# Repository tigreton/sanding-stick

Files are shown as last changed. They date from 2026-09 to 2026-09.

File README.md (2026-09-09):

# Sanding Stick — lijador modular paramétrico

Mango tipo bolígrafo + 14 cabezales intercambiables, para lijar impresiones 3D y
filigranas en madera. Impreso en Bambu Lab A1 Mini (180 × 180 × 180 mm).

**Diez versiones. Lo único que cambia entre ellas es cómo se engancha el cabezal.**
Formas, anchos, mangos y orientación de impresión son idénticos en las diez.

| | Unión | Gesto de cambio | Aguanta el tirón | Comprar algo |
|---|---|---|---|---|
| **v1** | Hexágono 6 AF a presión | tirar y empujar | regular | no |
| **v2** | Bayoneta de 1/4 de vuelta | meter y girar 90° | **sí, bloqueo axial** | no |
| **v3** | Rosca cuadrada Ø8 × paso 2 | 3 vueltas | **sí** | no |
| **v4** | Imán Ø6×3 + espiga en D | acercar | se separa al tirar | **15 imanes** |
| **v5** | Clip elástico de dos brazos | empujar hasta el clic | sí, hasta cierta fuerza | no |
| **v6** | Cola de milano transversal | deslizar hasta el clic | **sí, por geometría** | no |
| **v7** | Cono autoblocante de 12° | empujar y tirar | sí, por rozamiento | no |
| **v8** | Espiga y cuña transversal | meter y empujar la cuña | **sí, y regulable** | no |
| **v9** | Pinza cónica de cuatro dedos | meter y empujar el casquillo | **sí, y regulable** | no |
| **v10** | Doble espiga con clic | empujar hasta el clic | sí, pero espigas frágiles | no |

**Si sólo vas a imprimir una: la v2.** Es la única *probada* que combina cambio
rápido con bloqueo axial real, y no depende de comprar nada ni de que un brazo
elástico aguante mil ciclos.

**Si lo que te preocupa es que el cabezal se afloje lijando: la v6.** Es la única
cuya dirección de desmontaje no coincide con ninguna dirección de trabajo, y la
única en la que el tirón lo aguanta la forma —un destalonado— y no el rozamiento
ni un brazo elástico.

**Si no quieres calibrar nada: la v7.** Es la única sin holgura que acertar: un
cono se para donde le deja la interferencia y queda tocando en toda la
superficie, así que el error de impresión se convierte en profundidad de asiento
en vez de en juego. Sujeta por rozamiento, como la v1, pero sin el juego que
hace que la v1 se afloje.

**Si quieres poder reapretarla dentro de un año: la v8.** Es la única cuyo
apriete no lo fija un número del modelo sino cuánto empujas la cuña, con 7 mm de
recorrido por delante. A cambio es la que más debilita el cabezal.

La v9 hace lo mismo que la v8 sin pieza que se pueda perder, pero es la más
voluminosa y la que más pieza tiene que imprimir.

**La v10 es la que más superficie de apoyo tiene contra el hombro** —53,5 mm²,
que es lo que de verdad impide que el cabezal bascule— y la que menos exige a la
impresora: dos postes redondos y dos agujeros redondos. Pero **sus espigas son
frágiles**: se han roto dos veces durante la puesta a punto y aguantan 2,4 kg de
fuerza lateral contra los 8,8 de un vástago normal. La v6 da el 90 % de esa
corona con una parte macho maciza, así que para casi todo el mundo es mejor
opción.

Las v6 a v10 son nuevas y todavía no han pasado por la cama: empieza por su
`test_ajuste`.

Abre `visor_lijador.html` en el navegador para verlas y compararlas en 3D: están
las diez, con las tres piezas de la v8 y la v9 montadas. Se regenera con
`python3 web/_empaquetar.py` (sólo renderiza lo que falte; `--todo` desde cero).

---

## 1. Archivos

```
sanding_stick/
├── scad/
│   ├── sanding_stick.scad        v1 · hexágono a presión
│   ├── sanding_stick_v2.scad     v2 · bayoneta
│   ├── sanding_stick_v3.scad     v3 · rosca
│   ├── sanding_stick_v4.scad     v4 · imán
│   ├── sanding_stick_v5.scad     v5 · clip elástico
│   ├── sanding_stick_v6.scad     v6 · cola de milano transversal
│   ├── sanding_stick_v7.scad     v7 · cono autoblocante
│   ├── sanding_stick_v8.scad     v8 · espiga y cuña
│   ├── sanding_stick_v9.scad     v9 · pinza cónica
│   ├── sanding_stick_v10.scad    v10 · doble espiga
│   └── _generar_versiones.py     genera v2–v10 desde un esqueleto común
├── render.sh                     genera los STL de una versión o de todas (bash)
├── render.ps1                    lo mismo desde PowerShell, para Windows
├── test_rapido.sh                genera el kit de test mínimo → stl_test/
├── TEST_RAPIDO.md                qué imprimir para elegir enganche y formas
├── visor_lijador.html            visor 3D interactivo con las diez versiones (3 MB)
├── stl/                          STL a calidad final
├── preview_stl/vN/               18 piezas por versión, calidad de trabajo
├── png/                          renders de cada pieza
├── web/
│   ├── plantilla.html            el visor sin las mallas
│   ├── meshes.js                 170 mallas cuantizadas y comprimidas
│   └── _empaquetar.py            renderiza lo que falte y arma el visor
├── sanding_stick_v1.0.zip        instantánea congelada de la v1
├── sanding_stick_v1-v5.zip       instantánea de las cinco versiones
└── CHANGELOG.md · FUENTES.md · PUBLICAR.md · README.md · LICENSE
```

`preview_stl/` y `png/` no van al repositorio: se regeneran con `./render.sh`.
Sí están versionadas las diez piezas de calibración (`stl/vN/test_ajuste.stl`),
que es lo primero que hay que imprimir, guardadas como STL binario.

## 2. Lo que comparten las diez versiones

**El cabezal tiene que apoyar en el hombro del mango.** Es lo que impide que
bascule al lijar: sin apoyo va en voladizo sobre el vástago y el par lo mueve
dentro de la holgura. El hombro llega hasta Ø(12 − 2·`mango_chaflan_frontal`) y la
boca del cabezal acaba en Ø10,48 — así que **el chaflán frontal es un parámetro de
la unión, no un detalle estético**, y cada versión lo ajusta al avellanado de su
propia boca (la v2 lo baja a 0,3; la v1 apoya de sobra con 1,0).

Cuánta corona apoya de verdad en cada versión, integrado sobre la malla en el
plano de la boca y recortado a lo que alcanza el hombro:

| | Corona | |
|---|---:|---|
| **v10** doble espiga | **53,5 mm²** | dos taladros de Ø4,15 en vez de uno de Ø8,6 |
| **v6** cola de milano | **48,4 mm²** | la ranura ocupa poco del plano de la boca |
| v1 hexágono | 25,5 mm² | |
| v5 clip | 13,4 mm² | los dos planos dejan material cerca del eje |
| v8 cuña | 13,2 mm² | con `cun_avell` = 0,4 |
| v4 imán | 8,9 mm² | el plano de la chaveta en D |
| v9 pinza | 8,5 mm² | |
| v2 bayoneta | 1,6 mm² | apoya en filo, no en cara |
| v3 rosca | 0,0 mm² | |
| v7 cono | 0,0 mm² | **a propósito**: posiciona el cono, no el hombro |

Las tres últimas explican por sí solas por qué la v2 se aflojaba: su avellanado
de boca es más ancho que el borde que deja `cuerpo_chaflan`, así que la boca
acaba en filo y no en cara. Arreglarlo del todo pide bajar `cuerpo_chaflan` de
0,8 a 0,4, y eso son catorce cabezales a reimprimir — sigue pendiente. Las
versiones nuevas nacen ya con el avellanado ajustado.

### La falda exterior — `falda = 6`

Opción del esqueleto, no una versión: el cabezal se alarga 6 mm y envuelve por
fuera un tramo rebajado de la punta del mango (espiga Ø8,8, contrataladro Ø9,0).
Se activa con un parámetro y **vale para ocho de las diez uniones**:

```bash
openscad -o pala.stl -D 'pieza="cabezal"' -D falda=6 scad/sanding_stick_v2.scad
```

Hace dos cosas, y sólo una de ellas es un regalo:

**1 · Le devuelve la corona a las uniones que la tienen en filo.** Medido:

| | Corona | Inercia de la corona |
|---|---:|---:|
| v2 sin falda | 1,6 mm² | 22 mm⁴ |
| **v2 con falda** | **30,5 mm²** | **420 mm⁴** — 19 veces más |
| v6 sin falda | 48,5 mm² | 434 mm⁴ |
| v6 con falda | 27,2 mm² | 367 mm⁴ — un 15 % menos |
| v10 sin falda | 53,5 mm² | 415 mm⁴ |
| v10 con falda | 27,2 mm² | 367 mm⁴ — un 12 % menos |

Es decir: **rescate para la v2 a v5, y ligera pérdida para la v6 y la v10.** La
falda cambia un disco casi macizo por un anillo: gana radio y pierde área, y a
las que ya tenían disco no les compensa. No es una mejora universal.

**2 · Reduce a la mitad el basculamiento por holgura, y eso sí vale para todas.**
Sin falda, al cabezal lo guía sólo el taladro: 13 mm de base con 0,18 de holgura
son 1,59° de bamboleo. Con falda hay dos guías separadas, una a cada lado del
plano de la junta, y la base pasa de 13 a 19 mm: 0,84°.

**Lo que cuesta:** 6 mm más de herramienta y ~220 mm³ por cabezal (3,1 cm³ en los
catorce).

**No vale para la v7 ni para la v9.** En la v7 la corona de la falda apoyaría en
el hombro y le disputaría al cono el posicionamiento axial, que es justo lo que
esa unión evita a propósito. En la v9 es peor: el cono exterior de la pinza queda
enterrado 6 mm dentro de un tubo de Ø12 —medido, Ø11,12 a 7 mm de la boca— y el
casquillo no puede llegar a él.

Dos cotas de la falda están donde están por una razón, y las dos son el mismo
fallo de siempre: `falda_chaflan` no puede pasar de 0,3 ni `falda_ch_boca` de
0,3, porque con 0,6 y 0,8 los dos avellanados se comen la corona entera y la
boca vuelve a acabar en filo. `falda_pared` tampoco puede subir de 1,6: el
contrataladro tiene que ser más ancho que la hembra de la junta o no se puede
llegar a ella.

**La parte macho va en el mango y la hembra en el cabezal.** Es la decisión que
condiciona todo lo demás:

- Todos los cabezales se imprimen **planos, con la cara de lijado sobre la cama**.
  Esa cara sale lisa y perfectamente plana, que es lo que necesita para pegar la lija.
- Ningún cabezal necesita soportes en ninguna de las cinco versiones.
- El cuerpo del cabezal es Ø12 × 16 mm, enrasado con el mango, con el eje a 5,5 mm
  de la cama: eso deja un plano de apoyo de ~5 mm y se imprime estable.

**Catálogo de cabezales** (7 formas × 2 anchos):

| Cabezal | Cara útil | Para qué |
|---|---|---|
| Pala plana 0° | 16×40 / 8×40 | caras grandes, líneas de capa, planos largos |
| Pala 45° | 16×25 / 8×25 | chaflanes, romper aristas |
| Taco 90° | 16×16 / 8×16 | fondos y rincones, lijando a empuje |
| Triángulo | punta 30 / 22 mm | esquinas interiores, calados de marquetería |
| Prisma 3 caras | 3 caras de 16 / 8 | ranuras en V, molduras; tres caras útiles |
| Media caña convexa | R8 / R4 | interiores curvos, gargantas |
| Canal cóncavo | canal Ø12 / Ø5 | varillas, barrotes, cantos redondeados |

Cuando la cara es de 8 mm y el mango de 12, la paleta lleva un **hombro** que la
ensancha hasta Ø12 junto al cuerpo: refuerza el cuello, que es donde rompería.

**Tres mangos**, los tres compatibles con cualquier cabezal de su versión:

| | Envolvente | Volumen | Cómo se imprime |
|---|---|---|---|
| **recta** | Ø12 × 137 | 14,2 cm³ | de pie, con balsa |
| **ergonomica** | Ø11–14 × 137 | 15,2 cm³ | de pie, con balsa |
| **doble** | 149 × 12 × 9 | 11,9 cm³ | tumbado sobre la cara plana |

La variante doble tiene la parte macho en los dos extremos y un plano lateral: se
imprime en 9 mm de alto en vez de una torre de 137 mm, no rueda por la mesa y lleva
dos cabezales montados a la vez.

## 3. Las cinco uniones en detalle

### v1 · Hexágono a presión — `scad/sanding_stick.scad`

Espiga hexagonal de 6,00 mm entrecaras, 12 mm de agarre; hueco de 6,30 (holgura
0,15 mm por lado); chaflanes de 0,8 mm en espiga y boca. Seis caras planas impiden
que el cabezal gire al lijar de canto y estiran menos material que un cilindro.

*Calibrar:* `holgura`.

### v2 · Bayoneta de 1/4 de vuelta — `scad/sanding_stick_v2.scad`

Vástago Ø8,6 con dos ranuras en L; taladro Ø8,96 con dos tetones interiores. Se mete
a fondo y se gira 90° hasta el tope. **El canal no es horizontal: su techo baja
0,40 mm a lo largo del giro**, así que girar aprieta el cabezal contra el hombro del
mango. Es una cuña autoblocante y al entrar en el asiento pasa un resalte de
0,18 mm que se nota como un clic.

Los dos tetones van a ±90° del eje vertical, o sea horizontales sobre la cama:
ninguna de sus caras es un voladizo.

**El parámetro que decide si aguanta es `bay_juego_ax`** (0,05): el hueco que le
queda al tetón entre el suelo y el techo del canal. En la 2.0 valía 0,15 — más que
la propia muesca de retención — así que el tetón flotaba, la cuña no llegaba a
apretar y lijar de lado aflojaba la unión. Con 0,05, el tetón queda pinzado y la
muesca muerde 0,16 mm de verdad.

*Calibrar:* `bay_holgura` (0,18) para el ajuste radial. Si el giro va duro al final,
baja `bay_muesca` antes que nada; si baila, baja `bay_juego_ax`.

### v3 · Rosca cuadrada — `scad/sanding_stick_v3.scad`

Ø8 × paso 2, seis vueltas, filete cuadrado de 0,7 mm de profundidad. El perfil
cuadrado se imprime mucho mejor que el triangular (nada de puntas finas) y agarra
más superficie. Un piloto liso Ø8,6 × 2 centra antes de que la rosca engrane, y el
cabezal apoya en un hombro plano.

*Calibrar:* `ros_holgura` (0,25 radial) y `ros_hol_ax` (0,15 por flanco).

### v4 · Imán — `scad/sanding_stick_v4.scad`

Espiga Ø9 × 7,5 con una cara plana (chaveta en D) que impide el giro, y un imán de
neodimio **Ø6 × 3 mm** en la punta. Otro imán igual al fondo del taladro del cabezal,
a 0,3 mm del primero cuando está montado.

Necesitas 15 imanes: uno por mango y uno por cabezal. Se pegan con cianoacrilato.
**Acerca los dos imanes antes de encolar para marcar la polaridad** — si los pegas
al revés, el cabezal se repele.

*Calibrar:* `esp_holgura` (0,20). El alojamiento del imán es `mag_juego` = 0,20.

### v5 · Clip elástico — `scad/sanding_stick_v5.scad`

Vástago Ø8,6 partido por una ranura de 3,8 mm en dos brazos flexibles de 11,5 mm de
voladizo, cada uno con una pestaña de 0,6 mm que encaja en un rebaje interior del
cabezal. Rampas de 40° por los dos lados: entra y sale, no es un encaje permanente.
Dos caras planas laterales orientan la pieza y hacen de chaveta.

La deformación de trabajo del brazo es del **1,9 %** — recalculada con el método
que validó la rotura de la v10.0, tomando como voladizo la distancia real hasta la
pestaña y la sección real del brazo, que es un segmento circular y no un
rectángulo. Es tracción entre capas, así que **imprímelo en PETG**: en PLA está
por encima de donde rompe. Se salva de lo que le pasó a la v10.0 porque su brazo
tiene 13,2 mm² de sección contra los 2,9 de aquélla.

*Calibrar:* `snap_pest` (0,6). Si cuesta meterlo, baja a 0,5; si se suelta, sube a 0,7.

### v6 · Cola de milano transversal — `scad/sanding_stick_v6.scad`

La única unión de la familia que **no se enchufa**: el cabezal desliza de lado
sobre un carril de cola de milano en la punta del mango. Carril de 7,0 mm de
cresta × 5,0 de alto, flancos a 12° de la vertical, recorrido de 7,9 mm.

Las tres cosas que la hacen distinta:

**La dirección de desmontaje no es ninguna dirección de lijado.** Empujar y tirar
actúan a lo largo del mango; girar, alrededor de él. El cabezal sale
perpendicular a las dos, así que el propio gesto de lijar no puede desmontarlo.
Y con `cm_orient = 90` esa dirección es además la de la presión de lijado, que
mete el cabezal contra su tope en vez de sacarlo.

**El tirón lo aguanta la geometría, no el ajuste.** El destalonado de 12° hay que
romperlo para separar las piezas: no depende del rozamiento (v1, v4), ni de un
brazo elástico que se fatiga (v5), ni de que una holgura siga siendo la del
primer día. Un carril tampoco puede girar dentro de su ranura: el par de lijar de
canto lo bloquea la forma.

**Aprieta al final del recorrido.** El carril es cónico: la cresta se estrecha
0,7 mm desde el tope hasta la entrada (0,095 mm por milímetro) y la ranura del
cabezal se estrecha igual. Entra suelta y sólo aprieta en el último milímetro, y
por el ángulo del milano ese apriete empuja el cabezal contra el hombro del
mango. Es la misma cuña autoblocante de la v2, en línea recta.

En el sentido del deslizamiento la sujetan un tope duro por un lado y, por el
otro, un resalte de 0,10 mm en el extremo de entrada del carril. Para pasarlo el
cabezal tiene que levantarse ~0,45 mm del hombro, así que se nota como un clic y
no cede lijando de lado. El resalte va en la ENTRADA a propósito: sólo queda
cubierto en los últimos 1,5 mm, y no roza durante todo el recorrido.

*Ojo con la orientación:* con `cm_orient = 0` el carril desliza de lado, que es
más cómodo de cambiar, **pero los flancos quedan a 12° de la horizontal y el
cabezal necesita soportes justo en la superficie de ajuste**. Con 90 —el valor
por defecto— los flancos salen verticales y el cabezal no lleva ni un voladizo en
la zona de la unión (1,6 mm² frente a los 4,6 de la v2).

*Calibrar:* `cm_aprieto` (0,04, la interferencia total de flancos en el asiento).
Si el cabezal se queda corto y no llega al tope, bájalo; si llega pero baila,
súbelo. Si el clic cuesta demasiado, baja `cm_muesca` antes de tocar nada más.

### v7 · Cono autoblocante — `scad/sanding_stick_v7.scad`

La v1 hecha bien. Un cono de 12° de semiángulo, Ø8,4 en la base y 9 mm de largo,
en vez de un vástago cilíndrico.

**Es la única unión sin holgura que calibrar.** Un cilindro necesita hueco para
entrar, y ese hueco es exactamente el juego con el que después baila; un cono
entra hasta donde le deja la interferencia y se queda tocando en toda la
superficie. Cero juego radial, cero angular y cero basculamiento, sin depender
de acertar una décima ni de que la décima buena siga siéndolo con otro filamento.

Por debajo del ángulo de rozamiento del PLA (~17°) un cono es **autorretenedor**:
no se suelta solo y agarra con la fuerza que le hayas metido con el pulgar. Con
12° queda firme y sale de un tirón. Bajarlo agarra más, pero hay que golpearlo
para sacarlo y mueve el doble la profundidad de asiento.

Los dos planos de chaveta son **también cónicos**: escalan con el cono, así que
aprietan a la vez que él y el giro tampoco tiene juego. Un plano paralelo al eje
no serviría — se separaría de su cara en cuanto la profundidad variase.

**El cabezal no apoya en el hombro, a propósito.** Quien lo sitúa es el cono,
como en un cono Morse de máquina: si el hombro tocase, los dos se pelearían por
posicionar y el cono dejaría de apretar. Por eso el chaflán frontal es de 1,7 mm
en vez de 1,0 — la punta del mango acaba en Ø8,60 y el anillo de la boca del
cabezal empieza en Ø9,63, y no se rozan nunca.

**La contrapartida, dicha claramente:** la profundidad de asiento la pone el
ajuste, y cada 0,1 mm de error radial la mueve 0,47 mm. Como un taladro impreso
en horizontal tiende a salir estrecho, lo normal es que quede medio milímetro de
junta entre las dos piezas. No afecta a cómo sujeta —el cono agarra igual— y
cae dentro de la V que forman los dos chaflanes, que es donde menos canta. Si
te molesta, `con_retro` la cierra.

Dos topes de seguridad que con un ajuste normal no llegan a tocar: el taladro
deja 0,8 mm delante de la punta, y si el cono entrase muy suelto la boca del
cabezal apoyaría en el chaflán del mango medio milímetro más adentro, antes de
que la cuña pudiera abrir una pared de 1,6 mm.

*Calibrar:* `con_retro`, y sólo si te molesta la junta. Está en milímetros de
recorrido: `-0.3` mete el cabezal 0,3 mm más hacia el mango. **No cambia cómo
ajusta** — es la única versión en la que equivocarse en el parámetro no estropea
la unión, sólo mueve dónde queda la junta.

### v8 · Espiga y cuña transversal — `scad/sanding_stick_v8.scad`

La unión de carpintería de siempre, a escala de bolígrafo, y **la única con tres
piezas**: mango, cabezal y una cuña de 13,6 × 5 × 2,6–3,2 mm (177 mm³, se
imprime en un minuto).

El vástago lleva una ranura transversal y el cabezal un túnel alineado con ella.
La cuña entra de lado atravesando los dos: apoya por abajo en el suelo del túnel
del cabezal y por arriba en el techo de la ranura del vástago. Como es cónica
(1:12), empujarla separa esas dos caras y **tira del vástago hacia dentro**,
apretando el cabezal contra el hombro del mango.

**El apriete no lo fija el modelo, lo fijas tú.** Ninguna otra versión tiene eso:
en las demás, si la holgura se queda corta o la unión se desgasta, hay que
reimprimir. Aquí empujas la cuña medio milímetro más. Hay 7,2 mm de recorrido
(`cun_juego` dividido por la pendiente), y 1:12 está muy por debajo del ángulo de
rozamiento del PLA, así que no se sale sola.

**La cuña es además la chaveta.** Atraviesa el vástago, así que el giro lo bloquea
ella y el taladro puede ser un cilindro liso. Y con 13,6 mm de largo dentro de un
vástago de Ø8,6, el descuadre que permiten sus 0,08 de holgura lateral es de
0,34° — el largo de la cuña, no su holgura, es lo que fija el giro.

**Lo que cuesta, con los números medidos** sobre la sección del cabezal en la
banda del túnel, comparada con la sección intacta:

| | Área | I respecto a la presión de lijado | I lijando de lado |
|---|---|---|---|
| Intacta (a 4 mm de la boca) | 49,3 mm² | 659 mm⁴ | 706 mm⁴ |
| En la banda de la cuña (9 mm) | 32,7 mm² | 621 mm⁴ | 288 mm⁴ |
| **Pérdida** | **34 %** | **5,7 %** | **59 %** |

La orientación del túnel es la buena: quita material del eje neutro para la
flexión que produce la presión de lijado —la carga dominante— y sólo 5,7 % de
inercia. Girado 90° sería al revés. En esa dirección el momento en la banda es el
75 % del de la boca, así que **la banda no es la sección crítica lijando de
plano**: trabaja al 0,80 de lo que trabaja la boca.

Lijando de lado sí lo es: pierde el 59 % de inercia y queda a ~1,8 veces la
tensión de la boca. Son fuerzas de rozamiento, mucho menores que la presión, pero
es el punto por donde rompería.

**La cuña es el fusible.** Aguanta unos 90 N de precarga antes de doblarse, y con
la ventaja mecánica 12:1 un pulgar decidido llega ahí. Es lo que se rompe si te
pasas apretando, y es la pieza más barata de reimprimir de todo el proyecto.

Sobresale ~1,35 mm por cada lado. Es lo que permite empujarla para apretar y
golpearla para sacarla, y no hay forma de evitarlo en una unión de cuña.

*Calibrar:* nada. `cun_holgura` (0,15 radial) sólo tiene que dejar entrar el
vástago; quien quita el juego es la cuña. Si el taladro sale justo, súbela.

*Corregido en la 8.1:* el avellanado de la boca era de 0,8 y se comía el borde
que deja `cuerpo_chaflan`, así que la boca acababa en filo — 0,63 mm² de apoyo —
justo en la unión donde el hombro es contra lo que aprieta la cuña. Con
`cun_avell` = 0,4 son 13,2 mm² de cara plana.

### v9 · Pinza cónica — `scad/sanding_stick_v9.scad`

Una pinza de portaminas. La boca del cabezal va partida en cuatro dedos por
ranuras axiales y su exterior es un cono 1:8; un casquillo cónico de Ø14,6 × 6 mm
se empuja con el pulgar sobre ese cono y cierra los dedos sobre el vástago.

**El apriete no se agota.** Las demás versiones reparten un número fijo de
holgura, y cuando el uso se lo come no hay más que reimprimir. Aquí hay 2 mm de
recorrido de casquillo, cada milímetro cierra 0,125 mm de diámetro, y la unión se
puede reapretar durante toda la vida de la herramienta. La conicidad multiplica
por ocho la fuerza del pulgar y está muy por debajo del ángulo de rozamiento del
PLA, así que el casquillo no se afloja solo.

**La pinza va en el cabezal, no en el mango**, y no es un capricho. Al revés los
cabezales necesitarían un vástago macho saliendo en horizontal de la boca, y
dejarían de poder imprimirse planos sobre su cara de lijado, que es la decisión
de la que cuelga todo el proyecto. Dos consecuencias buenas: el mango es el más
simple de las nueve versiones —un cilindro liso de Ø8,6, sin una sola
característica— y cualquier cabezal se puede montar sobre **cualquier varilla de
Ø8,6**, por ejemplo un tubo largo para llegar al fondo de una caja.

**El casquillo no se pierde.** Por detrás no puede pasar al mango (su taladro
trasero es de Ø11,05 y el mango es de Ø12) y por delante topa con el cuerpo del
cabezal. Sólo sale con el cabezal desmontado, que es cuando toca limpiarlo. Es la
diferencia práctica con la cuña de la v8, que sí se puede perder.

Cada ranura acaba en un **taladro de alivio de Ø1,4**. Sin él la ranura muere en
un ángulo vivo, que es exactamente donde agrietaría un dedo después de unos
cuantos ciclos.

La deformación de trabajo del dedo es del **0,4 %** —cierra 0,075 mm sobre un
voladizo útil de 6 mm con 1,3 de pared—, menos de un tercio del 1,4 % del clip de
la v5. Esta pinza no se fatiga.

**Lo que cuesta:** es la más voluminosa, con un collar de Ø14,6 en una
herramienta de Ø12, y la que más volumen añade (355 mm³ de casquillo por mango).
Y el cabezal lleva cuatro ranuras abiertas de la boca hasta 10 mm que van a
recoger polvo de lijado.

*Calibrar:* nada. `pin_holgura` (0,15 diametral) sólo tiene que dejar entrar el
vástago con el casquillo suelto; el resto lo pone el pulgar.

### v10 · Doble espiga con clic — `scad/sanding_stick_v10.scad`

> **Esta unión se ha roto dos veces al imprimirla.** La 10.0 partía los brazos
> de las espigas al primer montaje; la 10.1, con las espigas ya macizas, partió
> una por la base al despegarla de la cama. Lo que sigue es la **10.2**. Sigue
> siendo, con diferencia, **la unión más frágil de las diez**: su espiga se parte
> con 2,4 kg de fuerza lateral en la punta, contra los 8,8 de un vástago Ø8,6.
> Elígela por su corona de apoyo, no por su resistencia. El historial completo
> está en el CHANGELOG.

Dos espigas **macizas** de Ø4,0 separadas 5,6 mm, con **raíz cónica** y una
garganta, y en el cabezal dos lengüetas flexibles con la pestaña.

**La raíz va cónica —Ø4,4 en el arranque, Ø4,0 a los 1,5 mm— y no es estética.**
Un ángulo vivo en el arranque multiplica por ~1,8 la tensión justo donde el
momento es máximo, que es exactamente por donde rompió la 10.1. El acuerdo
cóncavo de toda la vida no cabía: dos de R1,2 separados 5,6 mm se tocan entre sí
y se salen del hombro, y el rebaje que el cabezal necesitaría para librarlos se
comería la corona entera. La raíz cónica hace el mismo trabajo y el taladro del
cabezal la copia sin rebaje ninguno.

**El techo del concepto, por escrito:** con el cuerpo en Ø12, para que al cabezal
le queden 1,1 mm de pared por fuera de cada taladro y 1,45 de alma entre los dos,
la espiga no puede pasar de **Ø4,0**. Ahí se acaba lo que se puede reforzar. Es la unión que **reparte el
trabajo**: las espigas orientan y aguantan el par y el cortante, las lengüetas
sólo retienen, y quien impide que el cabezal bascule no es ninguna de las dos
cosas sino el hombro.

Y ahí está su argumento. La lección que costó la v2.2 fue que lo que impide
bascular es la corona de apoyo, no el vástago. Al cambiar un taladro de Ø8,6 por
dos de Ø3,55, la boca del cabezal deja de ser un anillo fino y pasa a ser un
disco casi macizo: **51,6 mm² apoyando contra el hombro, la mayor de las diez**,
frente a los 1,6 de la v2.

**Es la más fácil de imprimir bien.** Dos postes redondos y dos agujeros
redondos: no hay hélice, ni destalonado, ni tetones dentro de un canal, ni
collares de pared fina. Si hay una impresora o un filamento con los que las
demás uniones no acaban de salir, ésta va a salir.

**Lo que flexa vive en el cabezal, y eso no es un detalle.** El mango se imprime
de pie: cualquier voladizo suyo flexa *entre capas*, que es donde el PLA rompe
sobre el 1 %. El cabezal se imprime tumbado sobre su cara de lijado, así que una
lengüeta suya que flexe hacia los lados trabaja **dentro** del plano de la capa.
Es la lección que costó la 10.0, y vale para cualquier unión que se añada.

Y flexa poquísimo: la pestaña sobresale 0,18 dentro de un taladro que ya es
0,075 más ancho que la espiga, así que **lo que la lengüeta abre son 0,105 mm**.
Con 1,1 de pared, 3,0 de ancho y 5,1 de voladizo eso es **0,67 %**.

Ese mismo 0,105 es el escalón que retiene. Como la retención sale del *ángulo*
del canto y no de su profundidad, el canto de arriba de la garganta es corto a
propósito —0,15 para 0,24 de profundidad, unos 64°—: retiene de sobra sin
pedirle a la lengüeta ni una décima más de recorrido.

Las espigas van separadas en el eje que en el cabezal impreso es el
**horizontal**, para que las lengüetas caigan en los costados y no en la cara que
apoya en la cama. Se pierde algo de par de fuerzas contra la presión de lijado,
pero quien se come ese momento es la corona.

*Juego de giro:* vale holgura ÷ (separación ÷ 2) = 0,075/2,8 = **1,5°**. Bajar
`esp2_holgura` a 0,05 lo deja en 1,1°, a cambio de un ajuste más exigente.

**Lo que cuesta, y es mucho:** es la unión más frágil de las diez. La espiga se
parte con **2,4 kg** de fuerza lateral en la punta — cinco veces más que la 10.1,
pero un vástago Ø8,6 aguanta 8,8. Trátala con cuidado al despegarla de la cama y
no la elijas si vas a hacer palanca con la pala. Y el cabezal lleva cuatro
ranuras abiertas en los costados por las que entrará polvo.

*Calibrar:* `esp2_gar_sube` (0,15), que es lo que gradúa cuánto retiene: a 0,08
cuesta mucho sacarlo, a 0,30 sale solo. `esp2_pest` (0,18) sólo si el clic no se
nota — y sube 0,10 mm de recorrido de lengüeta por cada 0,10 que le añadas.
`esp2_largo` (9) y `esp2_d_raiz` (4,4) son los que deciden si la espiga aguanta:
no los bajes.

## 4. Calibra antes de imprimir el juego

**Si aún no sabes qué versión quieres, empieza por el kit de test rápido**
(`TEST_RAPIDO.md` · `stl_test/`): los cinco enganches y las siete formas
recortados a lo mínimo, para probarlos todos en un rato en vez de imprimir 45 cm³
a ciegas. La geometría de unión es la misma que la de las piezas reales.

1. Imprime el `test_ajuste.stl` **de la versión que hayas elegido** (5 min). Trae el
   macho y la hembra sueltos, con la geometría exacta de las piezas reales.
2. Prueba el encaje. Debe montar sin forzar y quedar firme.
3. Corrige **una sola variable**, la que dice «calibrar» en el apartado de tu versión.
4. Repite el test. **Sólo cuando encaje**, lanza `./render.sh vN`.

Cambiar la holgura después obliga a reimprimir los catorce cabezales, no el mango.

## 5. Ajustes de impresión

**Cabezales** — capa 0,16 mm · 4 perímetros · 30 % giroide · sin soportes ni balsa.
PLA vale (PETG en la v5, y también si vas a lijar en húmedo). Los catorce caben en
una bandeja: 45–50 cm³ según la versión.

**Mango** — capa 0,20 mm · 4 perímetros · 20 % · velocidad exterior ≤ 120 mm/s.
Recto y ergonómico **de pie con balsa**, con la parte macho hacia arriba (el chaflán
de punta evita así el «pie de elefante» en el encaje). Doble, tumbado.

## 6. Uso del modelo

**En Windows, usa PowerShell y `render.ps1`** — `render.sh` es bash y necesita Git
Bash o WSL. El `.ps1` busca `openscad.exe` en el PATH y en las rutas normales de
instalación; si lo tienes en otro sitio, `$env:OPENSCAD = "C:\ruta\openscad.exe"`.

```powershell
.\render.ps1 v2            # una versión completa, calidad final ($fn=64) → stl\v2\
.\render.ps1 todas         # las cinco
.\render.ps1 v2 preview    # rápido ($fn=48) → preview_stl\v2\
```

```bash
./render.sh v2            # lo mismo desde bash
./render.sh todas
./render.sh v3 preview    # rápido ($fn=48) + PNG de cada pieza

# una pieza suelta
openscad -o pala16_45.stl -D 'pieza="cabezal"' -D 'tipo="pala"' \
         -D ancho=16 -D angulo=45 scad/sanding_stick_v2.scad
```

Los dos scripts **avisan si no encuentran OpenSCAD y si alguna pieza no se ha
escrito**, en vez de recorrer las 18 en silencio y decir «Listo».

Calidad final es `$fn=64`, no 96: en un cilindro Ø12 el error de facetado con 64 es
de 0,007 mm — treinta veces menos de lo que puede expresar una boquilla de 0,4 — y
con 96 el mango tarda tres veces más en resolver los booleanos.

Parámetros comunes, todos al principio de cada `.scad` con su comentario:

| Parámetro | Por defecto | Qué hace |
|---|---|---|
| `pieza` | `"conjunto"` | `mango` · `cabezal` · `test_ajuste` · `conjunto` · `interferencia` |
| `variante_mango` | `"recta"` | `recta` · `ergonomica` · `doble` |
| `tipo` | `"pala"` | forma del cabezal (7 opciones) |
| `ancho` | `16` | ancho de la cara de lijado |
| `angulo` | `0` | 0 / 45 / 90 — sólo para `pala` |
| `mango_largo` | `125` | largo del mango sin la parte macho |
| `ranuras_num` | `7` | anillos de agarre |
| `largo_barra` | `40` | largo de prismas y medios tubos |
| `falda` | `0` | falda exterior; 6 la activa (ver apartado 2) |

`pieza="interferencia"` renderiza la intersección del cabezal con el mango montado:
su volumen debe ser prácticamente cero. Es la comprobación que garantiza que macho y
hembra casan sin chocar.

## 7. Añadir una undécima unión

Las versiones 2 a 10 se generan desde un esqueleto común con
`python3 scad/_generar_versiones.py`. Cada una sólo aporta cinco cosas, y una
sexta si necesita una pieza suelta:

```
junta_macho(sentido)   parte macho, base en z=0, crece hacia +Z (va en el mango)
junta_hembra_neg()     negativo a restar, marco de la boca del cabezal
junta_hembra_pos()     positivo a añadir después de restar (tetones, etc.)
junta_giro()           giro del mango en el conjunto montado
junta_d()              Ø nominal, para el plano del mango "doble"

junta_extra()          pieza suelta tumbada para imprimir  → pieza="extra"
junta_extra_montado()  la misma, colocada en el marco de la boca
```

Las dos últimas están vacías en todas menos en la v8 y la v9, y son las que
permiten que una unión lleve una tercera pieza sin tocar el esqueleto:
`pieza="extra"` la saca sola, el `test_ajuste` la incluye al lado y el `conjunto`
la pinta montada.

Un aviso de la v9: **un chaflán se resta como anillo, no como cono.** Restar un
`cylinder(r1 = R+0,5, r2 = R−0,5)` parece un chaflán y en realidad se lleva por
delante toda la pieza en su primer plano, porque ahí el radio del cono es mayor
que el de la pieza. Hay que restar la diferencia entre un cilindro grande y ese
cono. Se ve al instante en la envolvente: 5,51 mm de alto en una pieza de 6.

Escribe esos módulos en un bloque nuevo del generador y tienes las 18 piezas.

**Aviso al escribir una junta nueva:** el marco de la boca del cabezal está
**espejado en Z** respecto al del mango. Cualquier geometría con quiralidad —una
hélice, una bayoneta— hay que invertirla en la hembra, o macho y hembra no casan.
La comprobación `pieza="interferencia"` lo detecta al instante.

Ese espejo tiene un corolario que costó encontrar en la v6: **para orientar la
unión con un giro sobre el eje de la herramienta hay que girar el macho y la
hembra en sentidos contrarios** (`rotate([0,0,-cm_orient])` y
`rotate([0,0,+cm_orient])`). Si se giran igual, la parte simétrica encaja y la
asimétrica —la conicidad del carril— sale invertida.

**Lo que flexa va en el CABEZAL, no en el mango.** El mango se imprime de pie, así
que cualquier voladizo suyo flexa **entre capas**, y ahí el PLA rompe alrededor
del 1 %. El cabezal se imprime tumbado sobre su cara de lijado: una lengüeta suya
que flexe hacia los lados trabaja **dentro** del plano de la capa. La v10.0 puso
los brazos en el mango, prometió 0,56 % —eran 1,37 %— y se partió al primer
montaje a mano.

Y al calcular la deformación de un brazo: el voladizo es la distancia hasta la
**pestaña**, no la longitud de la ranura, y va al cuadrado; y la sección de un
brazo partido de una espiga redonda es un **segmento circular**, cuya fibra
exterior está más lejos del centroide que la mitad de su espesor. Los dos errores
juntos dan un número 2,4 veces optimista.

**Y comprueba los voladizos, no sólo la interferencia.** La v6 nació con los
flancos del milano a 12° de la horizontal: encajaba perfecto y era imposible de
imprimir sin soportes justo en la cara de ajuste. Se ve en dos líneas:

```python
m = trimesh.load("cabezal.stl"); n = m.face_normals
zmin = m.vertices[:,2].min()
cama = (m.vertices[m.faces][:,:,2] <= zmin + 0.05).all(axis=1)
print(m.area_faces[(n[:,2] < -0.7071) & ~cama].sum(), "mm² en voladizo")
```

## 8. Cómo pegar la lija

Cinta de doble cara fina o adhesivo de contacto en spray sobre la cara plana, y
recortar al ras con cúter apoyando el filo en el canto del cabezal. En los medios
tubos la lija se enrolla y los bordes se meten a presión dentro del canal, sin
pegamento: así se cambia en segundos.

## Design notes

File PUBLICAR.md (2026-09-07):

# Subir el repositorio

El repositorio ya está listo: dos commits, la etiqueta `v5.0` y el remoto
`origin` apuntando a `https://github.com/tigreton/sanding-stick.git`.

Sólo falta el `push`, y ese paso tiene que salir de tu máquina: requiere
autenticarse con tu cuenta de GitHub.

## Opción A · GitHub CLI (crea el repositorio y lo sube)

Con [GitHub CLI](https://cli.github.com) instalado, en esta carpeta:

```bash
gh auth login                       # una vez; abre el navegador, sin pegar tokens
git remote remove origin            # gh crea el remoto él mismo
gh repo create sanding-stick --public --source=. --push
git push origin v5.0
```

## Opción B · Crear el repositorio en la web

1. En [github.com/new](https://github.com/new): nombre `sanding-stick`.
   **No marques** «Add a README», «Add .gitignore» ni «Choose a license» — tiene
   que quedar vacío o el primer `push` chocará.
2. En esta carpeta, el remoto ya está puesto:

```bash
git push -u origin main
git push origin v5.0
```

La primera vez GitHub pedirá autenticación. La contraseña de la cuenta **no
sirve**: hace falta un token personal (Settings → Developer settings → Personal
access tokens) o tener GitHub CLI instalado, que gestiona las credenciales solo.

## Qué se sube y qué no

**Sí** (23 archivos, 5,4 MB): los cinco `.scad`, el generador, `render.sh`, el
visor 3D, la documentación, la licencia y las cinco piezas de calibración
`stl/vN/test_ajuste.stl` en STL binario.

**No** (`.gitignore`): `preview_stl/` y `png/` — 105 MB de archivos regenerables
con `./render.sh`. Y los `.zip`.

Si quieres el juego completo de STL publicado, lo habitual en proyectos de
impresión 3D no es meterlos en el repositorio sino colgarlos como **Release**.

`render.sh` ya exporta en STL binario, así que no hay que convertir nada:

```bash
./render.sh todas       # genera stl/v1..v5 a calidad final, en binario
gh release create v5.0 stl/v*/*.stl --title "Sanding Stick v5.0"
```

**En Windows**, `render.sh` es un script de bash: ejecútalo desde **Git Bash**
(viene con Git para Windows) o desde WSL. En PowerShell no funciona.

Y si lanzas el `gh release` desde PowerShell, el comodín hay que expandirlo a
mano, porque PowerShell no lo hace por los programas externos:

```powershell
./render.sh todas       # esto, desde Git Bash
gh release create v5.0 (Get-ChildItem stl\v*\*.stl).FullName --title "Sanding Stick v5.0"
```

## Licencia

Va con licencia **MIT**, permisiva y válida tanto para el código como para los
modelos. Si prefieres copyleft —CC BY-SA 4.0 o CERN-OHL-S son las habituales en
hardware libre, y obligan a compartir las modificaciones— sustituye el archivo
`LICENSE` antes de subirlo.

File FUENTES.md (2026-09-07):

# Fuentes e indicaciones — Sanding Stick

Registro de todo lo que entró en el proyecto: qué pediste, qué elegiste, qué se
consultó y por qué el diseño acabó así. 7 de septiembre de 2026, versiones 1 a 5.

---

## 1. Petición original (literal)

> quiero un "sanding stick" formado por el mango y el cabezal.
>
> El mago es igual para todo, del tamaño algo asi como un boligrafo.
>
> El cabezal, que debe ser intercambiable, tiene diferentes cabezas. Unas
> totalmente planas y a 90 grados, otras a 45. Otras a 0 grados. Tiene diferentes
> formas, un rectangulo, un triangulo, forma de medio tubo etc...
>
> La idea que se pueda pegar un trozo de papel de lija y poder lijar elementos de
> impresiones 3d o filigranas en madera. Presentamelo también primero con varios
> diseños 2 o 3D antes de hacer obtener el stl final.
>
> Guarda las fuentes y las indicaciones que hayas usado

## 2. Decisiones que tomaste

| Pregunta | Respuesta |
|---|---|
| Unión mango–cabezal | **Espiga hexagonal a presión.** Guardar las otras tres opciones para después |
| Ancho de la cara de lijado | **Varios anchos**: cada forma en 8 y 16 mm |
| Medio tubo | **Ambos**: uno convexo y uno cóncavo |
| Forma del mango | **Cilíndrico con ranuras** de agarre |

Opciones aparcadas en aquel momento a petición tuya —rosca, bayoneta e imán— y
retomadas después:

| Petición posterior | Resultado |
|---|---|
| «guárdalo todo esto como versión 1» | v1 congelada en `sanding_stick_v1.0.zip` |
| «como versión 2, quiero otro tipo de enganche» | v2, **bayoneta de 1/4 de vuelta** (elegida por ti entre cuatro opciones) |
| «cuando termines, haz las otras tres versiones» | v3 rosca, v4 imán, v5 clip elástico — las tres restantes de aquella lista |

También elegiste tener la v2 en un **archivo `.scad` aparte**, no como parámetro
dentro del de la v1. Al llegar a cinco versiones eso se resolvió con un generador
(`scad/_generar_versiones.py`): cinco archivos independientes y autocontenidos, pero
un solo esqueleto que mantener.

## 3. Contexto de proyecto reutilizado

De la base de conocimiento «diseños 3d» de tus conversaciones anteriores:

- Impresora **Bambu Lab A1 Mini**, volumen 180 × 180 × 180 mm → toda pieza debe
  caber ahí; de ahí la variante de mango tumbado.
- Flujo de trabajo ya establecido: **OpenSCAD paramétrico**, render sin pantalla
  con `xvfb-run` + `openscad -o`. El modelo sigue ese mismo patrón (parámetros
  con nombre arriba del archivo, una sola fuente para todas las piezas).
- Aprendizaje de las bandejas Leuchtturm: los agujeros y encajes necesitan
  **material sólido alrededor** para anclar; aquí se traduce en el cuerpo macizo
  de Ø12 × 16 mm del cabezal y en el hombro de las palas de 8 mm.

## 4. Fuentes externas consultadas

**Tolerancias de ajuste a presión en FDM** — se buscó para fijar el valor de
`holgura` con un criterio, no a ojo. Los resultados coinciden en un rango de
**0,05–0,15 mm por lado** para un press fit en FDM, en añadir un **chaflán o
radio de entrada** en eje y agujero para guiar el montaje y evitar agrietar la
pared, y en que las **geometrías hexagonales o cuadradas funcionan mejor** que
las cilíndricas porque exigen estirar menos material. También insisten en
imprimir una probeta antes de tirar la serie.

→ Decisión: `holgura = 0.15` (extremo alto del rango, porque el cabezal se cambia
muchas veces y un ajuste demasiado apretado acabaría partiendo la pared),
chaflanes de 0,8 mm en espiga y hueco, y pieza de calibración `test_ajuste.stl`
como primer paso obligatorio.

- [3D Printing Tolerances: Designing Gaps for Press Fits — Zbotic](https://zbotic.in/3d-printing-tolerances-designing-gaps-for-press-fits-threads-and-snap-fits/)
- [Engineering Fits: How to Design for 3D Printed Assemblies — AON3D](https://www.aon3d.com/applications/engineering-fits-how-to-design-for-3d-printed-assemblies/)
- [FDM 3D Printing Tolerances & Clearances — Sovol](https://www.sovol3d.com/blogs/news/fdm-3d-printing-tolerances-clearances-how-to-design-parts-that-fit)
- [Press-Fit Tolerances for 3D Printing — Creative3DP](https://tools.creative3dp.com/blog/press-fit-tolerances-3d-printing/)

**Volumen de impresión de la A1 Mini** — confirmado en la ficha técnica oficial:
180 × 180 × 180 mm.

- [Bambu Lab A1 mini — Technical Specifications](https://bambulab.com/en/a1-mini/tech-specs)
- [Ficha técnica A1 mini (PDF, Bambu Lab)](https://store.bblcdn.com/6cddc28fcb5a4a34975cfc7a23c83491.pdf)

**Granos de lija sugeridos** en el catálogo (P180–P800) proceden de la escala FEPA
P de uso común en acabado de impresiones 3D y madera; no se tomaron de una fuente
concreta y son una recomendación de partida, no una especificación.

## 5. Decisiones de diseño y su motivo

| Decisión | Motivo |
|---|---|
| Espiga en el mango, hueco en el cabezal | Permite imprimir **todos** los cabezales con la cara de lijado sobre la cama: sale plana y lisa, sin soportes |
| Hexágono en vez de cilindro | No gira al lijar de canto; estira menos material al entrar (mejor press fit en FDM) |
| 12 mm de agarre | Suficiente palanca para que el cabezal no cabecee; el cuerpo de 16 mm deja 3,5 mm de pared en el fondo |
| Cuerpo del cabezal Ø12 = Ø del mango | El conjunto queda enrasado, sin escalón donde engancharse |
| Eje del cuerpo a 5,5 mm de la cama | Genera un plano de apoyo de ~5 mm bajo el cuerpo: se imprime estable sin soportes |
| Hombro en las palas de 8 mm | Sin él, el cuello Ø12 → 8 mm dejaba geometría degenerada y un punto débil |
| Base del cuello Ø11,4 (0,6 menos que el cuerpo) | Evita que la superficie del `hull()` quede tangente al cilindro; sin esto una malla salía no-manifold |
| Tercera variante de mango (doble, tumbado) | Una torre de 137 mm y 12 mm de base en una A1 Mini es imprimible pero esbelta; esta variante lo resuelve por geometría |

## 6. Verificación hecha

- Las 18 mallas se comprobaron con `trimesh`: **todas estancas** (`is_watertight`)
  tras normalizar la precisión del STL ASCII, y OpenSCAD reporta `Simple: yes` en
  todas.
- Envolventes comprobadas contra 180 × 180 × 180 mm: la pieza mayor es el mango
  doble, 149 mm.
- Dos fallos detectados y corregidos en el proceso: `cabezal_pala_8_45` con 8
  aristas no-manifold en la tangencia cuello/cuerpo, y `cabezal_triangulo_8` con
  vértices sin fusionar. Ambos resueltos en el modelo, no en la malla.
- Montaje mango + cabezal verificado a 0°, 45° y 90° mediante render del módulo
  `conjunto()` (ver `png/conjunto_16_*.png`).

## 7. Herramientas

OpenSCAD 2021.01 (AppImage, render sin pantalla con `xvfb-run`) · Python 3 con
`trimesh` para la verificación de mallas · `three.js` r128 y `pako` 2.1.0 en el
visor HTML.

---

## 8. Lo aprendido al hacer las cinco uniones

Tres problemas que no se ven venir y que aparecieron al modelar juntas distintas
sobre el mismo esqueleto. Quedan aquí porque volverán a aparecer con la sexta:

**Quiralidad del marco de la boca.** El taladro del cabezal se construye con
`mirror([0,0,1])`, así que ese marco está espejado respecto al del mango. Cualquier
geometría con «mano» —una hélice de rosca, el canal de una bayoneta— sale invertida
en la hembra si se escribe igual que en el macho. En la v3 costó 44 mm³ de
interferencia hasta dar con ello; la solución es invertir la hélice **y** girarla
180°, porque el espejo no es sólo un cambio de signo del ángulo.

**Negativos que sólo se tocan.** Cuando dos sólidos que se van a restar comparten
exactamente un plano (el taladro acabando justo donde empieza el alojamiento del
imán, o el piloto justo donde empieza la rosca), CGAL no los une: deja una cavidad
cerrada dentro de la pieza. Pasó en la v3 y en la v4. Hay que solaparlos en volumen,
aunque sea 0,4 mm.

**Superficies tangentes.** Cuando la superficie reglada de un `hull()` queda
exactamente tangente a un cilindro, aparecen aristas compartidas por cuatro caras.
Se resuelve haciendo la base del `hull()` 0,6 mm más pequeña que el cilindro, para
que nunca lleguen a tocarse.

**Comprobación que lo detecta todo.** `pieza="interferencia"` renderiza la
intersección del cabezal con el mango montado. Su volumen debe ser cero, o justo el
apriete que se haya buscado a propósito. Es una comprobación de dos segundos que
encuentra en el acto lo que a ojo pasa desapercibido.

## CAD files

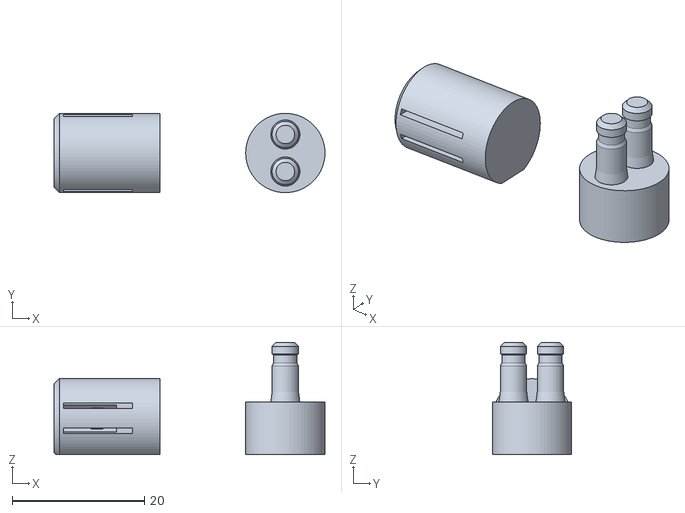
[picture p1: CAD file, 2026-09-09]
stl/v10/test_ajuste.stl
41.0 x 12.0 x 17.0

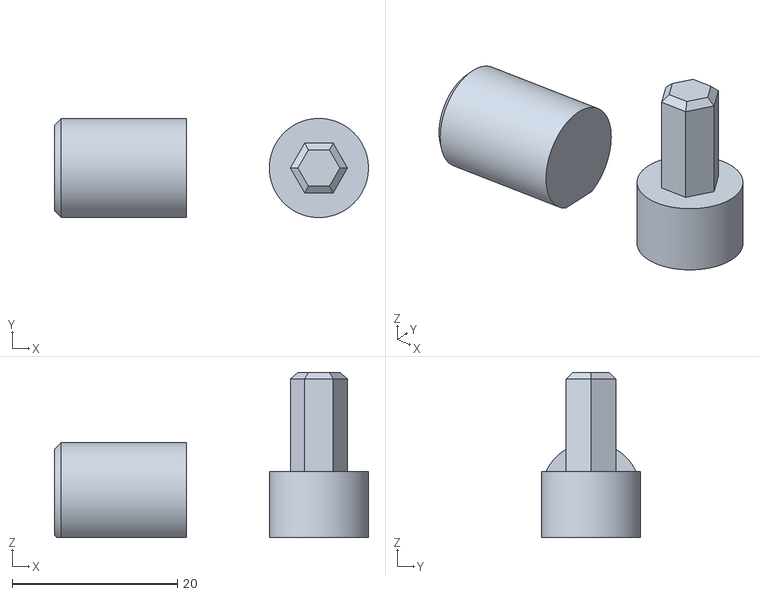
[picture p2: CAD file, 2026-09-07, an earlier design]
stl/v1/test_ajuste.stl
38.0 x 12.0 x 20.0

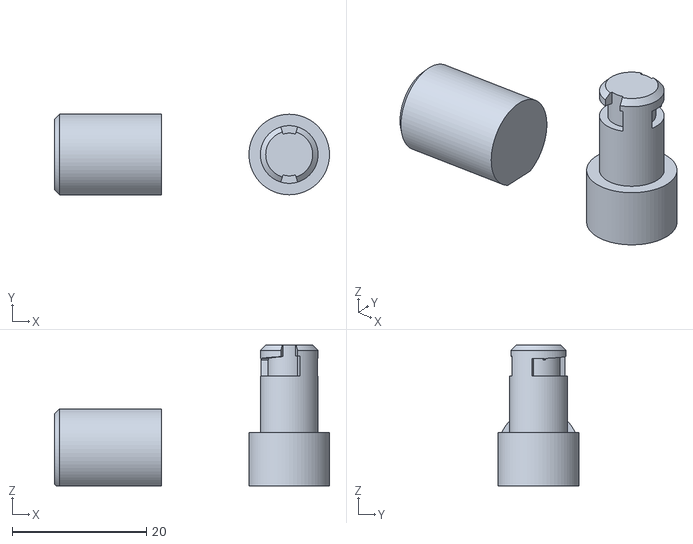
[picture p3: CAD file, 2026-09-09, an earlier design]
stl/v2/test_ajuste.stl
41.0 x 12.0 x 21.0

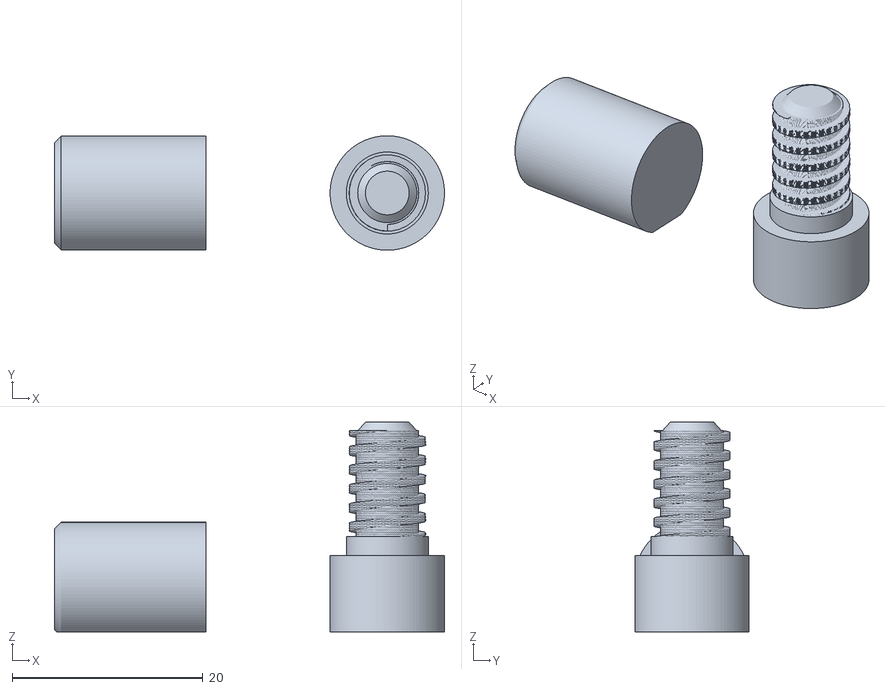
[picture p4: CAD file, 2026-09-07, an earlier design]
stl/v3/test_ajuste.stl
40.9 x 12.0 x 22.0

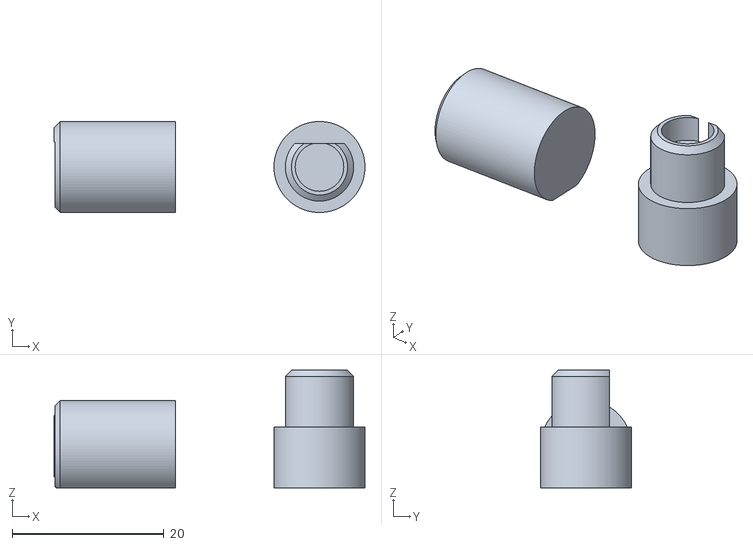
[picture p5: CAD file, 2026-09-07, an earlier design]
stl/v4/test_ajuste.stl
41.0 x 12.0 x 15.5

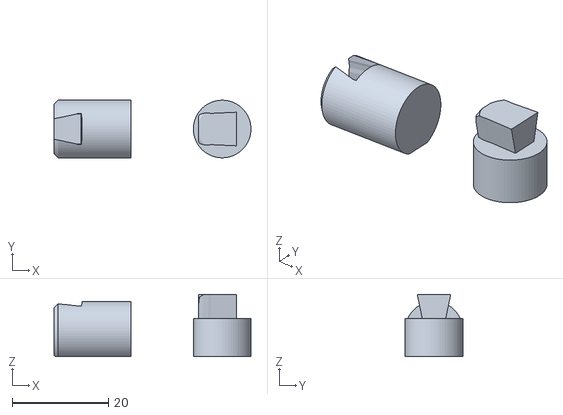
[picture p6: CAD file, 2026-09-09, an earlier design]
stl/v6/test_ajuste.stl
41.0 x 12.0 x 13.0

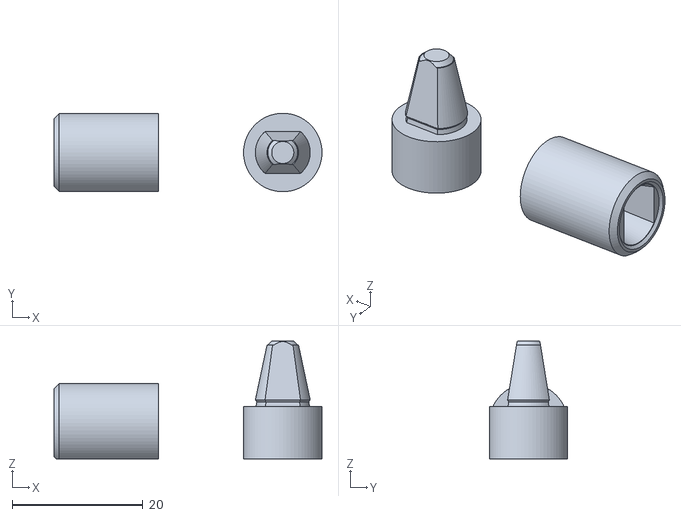
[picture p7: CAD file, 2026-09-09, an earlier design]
stl/v7/test_ajuste.stl
41.0 x 12.0 x 18.0

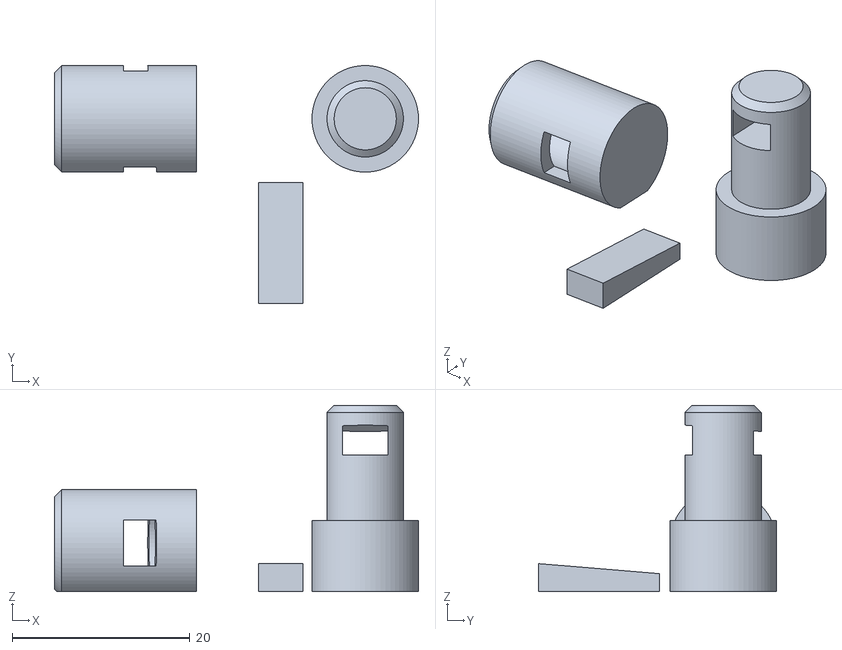
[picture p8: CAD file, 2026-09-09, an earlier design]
stl/v8/test_ajuste.stl
41.0 x 26.8 x 21.0

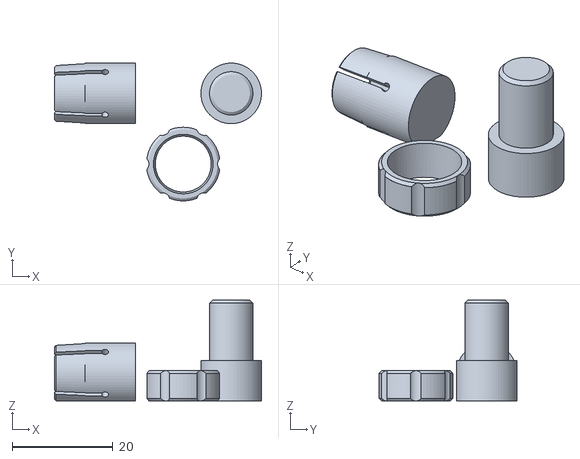
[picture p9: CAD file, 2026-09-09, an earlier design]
stl/v9/test_ajuste.stl
41.0 x 27.3 x 20.0

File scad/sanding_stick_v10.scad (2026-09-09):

// =====================================================================
//  SANDING STICK 2ESPIGAS — v10 · unión de DOBLE ESPIGA con clic
//  Versión 10.1 · 9 de septiembre de 2026 · Jorge (con Claude) · OpenSCAD 2021.01+
//
//  v10.2 — LA 10.1 TAMBIÉN SE ROMPIÓ, y por otro sitio: una espiga se partió
//  por la BASE al despegar la pieza de la cama. Las espigas macizas de Ø3,4
//  eran voladizos verticales de 12 mm que llegaban al hombro en ángulo vivo, y
//  con la raíz trabajando entre capas eso son 0,5 kg de fuerza lateral en la
//  punta. Un vástago Ø8,6 de las otras versiones aguanta 8,8.
//
//  Tres cambios, y los tres van al mismo sitio — la tensión en la raíz, que
//  vale M/W y crece con el largo y con el ángulo vivo:
//    · Ø3,4 → Ø4,0, el máximo que deja la geometría (ver abajo): W ×1,6
//    · 12 → 9 mm de largo: momento ×0,75
//    · RAÍZ CÓNICA de Ø4,4 en 1,5 mm en vez de ángulo vivo: mata el
//      concentrador (Kt de 1,8 a 1,2) y engorda la sección justo donde rompe
//  Juntos: de 0,5 a 2,4 kg. Cinco veces, y sigue siendo la unión más frágil de
//  las diez — eso hay que saberlo al elegirla.
//
//  El acuerdo cóncavo de toda la vida NO CABÍA: dos de R1,2 separados 5,6 mm se
//  tocan entre sí y se salen del hombro, y el rebaje que el cabezal necesitaría
//  para librarlos se comería la corona de apoyo entera. La raíz cónica hace el
//  mismo trabajo y el taladro del cabezal la copia sin rebaje ninguno.
//
//  EL TECHO DEL CONCEPTO, para que quede escrito: con el cuerpo en Ø12, para
//  que al cabezal le queden 1,1 mm de pared por fuera de cada taladro y 1,45 de
//  alma entre los dos, la espiga no puede pasar de Ø4,0. No hay más margen.
//
//  v10.1 — LA 10.0 SE ROMPÍA. Las espigas iban partidas en dos brazos cada una
//  y al primer montaje a mano se partieron. La ficha decía 0,56 % de
//  deformación y era falso por dos motivos: se tomó como voladizo la ranura
//  entera (9 mm) en vez de la distancia real hasta la pestaña (6,2), y se trató
//  la sección como un rectángulo de 1,2 cuando es un segmento circular con la
//  fibra exterior a 0,70 del centroide. El número real era 1,37 %.
//
//  Pero el fallo de fondo era otro, y es el que hay que recordar: **el brazo
//  era un voladizo vertical en una pieza que se imprime de pie**, así que la
//  tracción iba ENTRE CAPAS, que es donde el PLA rompe sobre el 1 %. El clip de
//  la v5 trabaja aún peor (1,9 %) pero con 4,6 veces más sección — y por eso su
//  ficha lleva desde el principio el aviso de imprimirlo en PETG.
//
//  La regla que sale de aquí: **lo que flexa va en el CABEZAL, no en el mango.**
//  El mango se imprime de pie y cualquier voladizo suyo flexa entre capas; el
//  cabezal se imprime tumbado sobre su cara de lijado, así que una lengüeta suya
//  que flexe hacia los lados trabaja DENTRO del plano de la capa.
//
//  Así queda: las espigas son MACIZAS —9,08 mm² cada una, no hay nada que
//  romper— y llevan una garganta. Quien flexa es el cabezal: la pared exterior
//  sobre cada taladro, liberada por dos ranuras, hace de lengüeta y lleva la
//  pestaña.
//
//  Y flexa poquísimo: la pestaña sobresale 0,18 dentro de un taladro que ya es
//  0,075 más ancho que la espiga, así que **lo que la lengüeta tiene que
//  abrirse es 0,105 mm**, no 0,18. Con 1,5 de pared, 3,0 de ancho y 7,0 de
//  voladizo eso son 0,49 % de deformación, y encima en el plano bueno. Frente
//  al 1,37 % entre capas de la 10.0.
//
//  Ese mismo 0,105 es el escalón que retiene. Como la retención sale del
//  ÁNGULO del canto y no de su profundidad, el canto de arriba es corto a
//  propósito (0,15 para 0,24 de garganta, unos 64°): retiene de sobra sin
//  pedirle a la lengüeta ni una décima más de recorrido. `esp2_gar_sube` es el
//  parámetro con el que se gradúa — a 0,08 cuesta mucho sacarlo, a 0,30 sale
//  solo.
//
//  Las espigas se separan ahora en el eje que en el cabezal impreso es el
//  HORIZONTAL, no el vertical: así las lengüetas caen en los costados y no en
//  la cara que apoya en la cama. Se pierde algo de par de fuerzas contra la
//  presión de lijado, pero quien se come ese momento es la corona de apoyo de
//  51,6 mm², que sigue siendo la mayor de las diez.
// =====================================================================

/* [Pieza a generar] */
pieza = "conjunto";           // ["mango","cabezal","test_ajuste","conjunto","interferencia","extra"]
                              // "extra" es la pieza suelta de las uniones que la
                              // necesitan (la cuña de la v8); vacía en las demás
variante_mango = "recta";     // ["recta","ergonomica","doble"]
giro_vista = 1;               // 1 = montado y bloqueado · 0 = alineado para insertar

/* [Cabezal] */
tipo = "pala";                // ["pala","triangulo","prisma_tri","medio_tubo_convexo","medio_tubo_concavo"]
ancho = 16;                   // ancho de la cara de lijado (8 ó 16 recomendados)
angulo = 0;                   // 0 | 45 | 90   (solo para tipo "pala")
largo_pala = -1;              // -1 = automático (40 a 0°, 25 a 45°, 16 a 90°)
espesor = -1;                 // -1 = automático (3 mm si ancho<=10, si no 4 mm)
radio_esquinas = 1.5;
largo_barra = 40;             // longitud de prismas y medios tubos
pared_canal = -1;
fondo_canal = 2;

/* [Mango] */
mango_diametro = 12;
mango_largo = 125;
mango_chaflan = 1.5;
mango_chaflan_frontal = 1.0;  // Es lo que le queda de asiento al cabezal: el hombro
                              // llega hasta Ø(12 - 2*chaflán). Cada versión lo ajusta
                              // a la boca de SU cabezal (la v2 lo baja a 0,3).
ranuras_num = 7;
ranuras_ancho = 1.6;
ranuras_prof = 0.6;
ranuras_paso = 4;
ranuras_inicio = 14;
plano_antirrodadura = 0;
ergo_d_frente = 11;
ergo_d_max = 14;
ergo_pos_max = 55;
ergo_d_atras = 10.5;

/* [Falda exterior — opcional, vale para las diez uniones] */
// Con falda > 0 el cabezal envuelve por fuera un tramo rebajado de la punta del
// mango. Traslada la corona de apoyo de Ø8,8–10,4 a Ø9,8–11,2: misma unión, el
// doble de inercia contra el basculamiento, y una guía radial más que alarga la
// base de apoyo por delante del plano de la junta en vez de por detrás.
// Cuesta `falda` mm de longitud de herramienta y ~240 mm³ por cabezal.
falda = 0;                    // longitud de la falda (0 = sin falda; 6 es lo probado)
falda_pared = 1.6;            // pared de la falda: la espiga queda en Ø(12 - 2·pared).
                              // No subirlo: el contrataladro tiene que ser más ancho
                              // que la hembra de la junta o no se puede llegar a ella
falda_juego = 0.10;           // holgura radial entre falda y espiga
falda_chaflan = 0.3;          // chaflán de entrada de la espiga y de la falda. Con 0,6
                              // el avellanado se comía la corona entera: mismo fallo
                              // que la boca en filo de la v2.2
falda_ch_boca = 0.3;          // chaflán exterior de la boca cuando hay falda. El 0,8
                              // de cuerpo_chaflan dejaría la corona en 9 mm²

/* [Cuerpo del cabezal] */
cuerpo_d = 12;
cuerpo_largo = 16;
cuerpo_zc = 5.5;
cuerpo_chaflan = 0.8;
cuello = 8;
cuello_90 = 3;

/* [Calidad] */
$fn = 64;
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

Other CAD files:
stl/v5/test_ajuste.stl
scad/sanding_stick.scad
scad/sanding_stick_v2.scad
scad/sanding_stick_v3.scad
scad/sanding_stick_v4.scad
scad/sanding_stick_v5.scad
scad/sanding_stick_v6.scad
scad/sanding_stick_v7.scad
scad/sanding_stick_v8.scad
scad/sanding_stick_v9.scad

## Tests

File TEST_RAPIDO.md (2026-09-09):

# Kit de test rápido

Piezas mínimas para decidir **qué enganche** y **qué formas** quieres antes de
imprimir el juego completo (que son 45–50 cm³ y unas cinco horas).

Todo está en `stl_test/`. **La geometría de unión es exactamente la de las piezas
reales**: lo único recortado es lo que no influye en el encaje — el mango pasa de
125 a 30 mm y la cara de lijado de 40 a 18 mm. Si aquí encaja, encaja en el juego
final.

---

## Paso 1 · ¿Qué enganche? (≈2 h, 26 cm³ las diez)

Cada `test_ajuste_vN.stl` trae el cuerpo con la hembra y un tapón con el macho,
sueltos — y en la v8 y la v9, también su tercera pieza.

| Pieza | cm³ | Unión |
|---|---|---|
| `test_ajuste_v1` | 2,60 | hexágono a presión |
| `test_ajuste_v2` | 2,50 | bayoneta 1/4 de vuelta |
| `test_ajuste_v3` | 2,50 | rosca cuadrada |
| `test_ajuste_v4` | 2,39 | imán + chaveta en D |
| `test_ajuste_v5` | 2,25 | clip elástico |
| `test_ajuste_v6` | 2,61 | cola de milano transversal |
| `test_ajuste_v7` | 2,65 | cono autoblocante |
| `test_ajuste_v8` | 2,86 | espiga y cuña · **lleva cuña** |
| `test_ajuste_v9` | 2,86 | pinza cónica · **lleva casquillo** |
| `test_ajuste_v10` | 2,56 | doble espiga con clic |

Diez ya no caben en «un rato». Para imprimir sólo unas cuantas:

```bash
VERS="v10 v6 v7" ./test_rapido.sh v6
```

Ese trío es un buen primer corte: la **v10** es la que mejor sale en cualquier
impresora, la **v6** la que mejor aguanta el uso y la **v7** la única que no tiene
holgura que calibrar. Si sale bien la v10 y mal alguna otra, el problema es de
calibración, no del diseño.

Móntalos y desmóntalos veinte veces. Lo que buscas: que entre sin forzar, que
quede firme, y que el gesto no te moleste. **La v4 necesita dos imanes Ø6×3** para
probarla de verdad; sin ellos sólo comprueba que la espiga entra.

Estas piezas también están versionadas a calidad final en
`stl/vN/test_ajuste.stl`: si no tienes OpenSCAD instalado, imprime ésas.

**Ojo con lo que mide esta pieza.** Su tapón es un cilindro Ø12 sin chaflán, así
que apoya en todo el anillo de la boca del cabezal — más de lo que apoyaba el
mango hasta la corrección del 8 de septiembre. Sirve para calibrar holguras; para
juzgar cuánto agarra de verdad, hay que ir al paso 2.

Si alguno va duro o baila, corrige **una sola variable** (la que dice «calibrar»
en el README de esa versión) y reimprime sólo esa pieza.

### Si vienes de la v2.0

`mango_corto_v2.stl` y `test_ajuste_v2.stl` son ya de la **v2.1**, que corrige el
aflojado al lijar de lado. El cambio está sólo en la parte macho: **reimprime el
mango y sigue usando los cabezales que ya tienes**.

## Paso 2 · Con el mango en la mano (≈45 min por versión, 6,5 cm³)

De las dos o tres finalistas, imprime la pareja:

- `mango_corto_vN.stl` — Ø12 × 43 mm, cuatro ranuras. De pie, con balsa.
- `cabezal_testigo_vN.stl` — pala plana de 16 × 18 mm. Plano, cara de lijado abajo.

Es el gesto real de cambio de cabezal, con el par que hace un mango de verdad.
Pega un trozo de lija en el testigo y lija algo: el enganche que aguanta el tirón
lateral se nota en treinta segundos.

## Paso 3 · ¿Qué formas necesitas? (≈1,5 h, 24 cm³)

`stl_test/formas_v2/` trae las siete formas recortadas a 18 mm de cara útil, más
el mango corto. Están generadas en la **v2**; si eliges otra versión, regenéralas:

```bash
./test_rapido.sh v3 solo      # → stl_test/formas_v3/
```

| Pieza | cm³ | Para qué |
|---|---|---|
| `pala_16_0` | 2,47 | caras grandes, líneas de capa |
| `pala_16_45` | 2,30 | chaflanes |
| `pala_16_90` | 2,90 | fondos y rincones |
| `triangulo_16` | 2,22 | esquinas interiores |
| `prisma_tri_16` | 3,10 | ranuras en V |
| `medio_tubo_convexo_16` | 2,90 | interiores curvos |
| `medio_tubo_concavo_16` | 2,87 | varillas y cantos |
| `pala_8_0` | 1,80 | ¿te hace falta la serie estrecha de 8 mm? |
| `mango_corto` | 3,90 | — |

Lija con ellas una pieza impresa de verdad durante un rato y tacha las que no
uses. En el juego final imprimes sólo las que sobrevivan, ya con la cara larga
(40 mm) y en los dos anchos.

---

## Impresión

Cabezales y test de ajuste: **0,16 mm · 4 perímetros · 25 % · sin soportes ni
balsa**, cara de lijado sobre la cama. Mangos: **0,20 mm · 4 perímetros · 20 %,
de pie con balsa**, la parte macho arriba. PLA vale para todo; la v5 mejor en PETG.

Las cifras de tiempo son orientativas — mándalo al laminador y hazle caso a él.

## Regenerar el kit

```bash
./test_rapido.sh          # enganches v1..v5 + formas en v2
./test_rapido.sh v3       # enganches v1..v5 + formas en v3
./test_rapido.sh v3 solo  # sólo las formas de la v3
```

Requiere `openscad` en el PATH. Los STL salen a `$fn=48`: suficiente para probar
el ajuste, y la mitad de tiempo de render que la calidad final.

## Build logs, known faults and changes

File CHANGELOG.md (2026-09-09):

# Historial de versiones — Sanding Stick

Todas las versiones comparten formas de cabezal, anchos, mangos y orientación de
impresión. Lo único que cambia es la unión entre mango y cabezal.

---

## v10.4 — La v10 se rompió otra vez, ahora por la base · 10 de septiembre de 2026

Segunda rotura, y por sitio distinto: con las espigas ya macizas, **una se partió
por la base al despegar la pieza de la cama**.

### El número

La raíz de una espiga es un voladizo vertical en una pieza impresa de pie, así
que trabaja **entre capas** (~30 MPa). Con Ø3,4, 12 mm de largo y llegando al
hombro en **ángulo vivo** —un concentrador de ~1,8—:

```
2 × Ø3,4 × 12, ángulo vivo (v10.1)     W = 3,86 mm³    rompe a  5,4 N  (0,5 kg)
2 × Ø4,4 raíz cónica × 9   (v10.2)     W = 8,36 mm³    rompe a 23,2 N  (2,4 kg)
un vástago Ø8,6 × 12 (v2, v6, v8…)     W = 62,4 mm³    rompe a 86,7 N  (8,8 kg)
```

Medio kilo de fuerza lateral en la punta. Eso no es una unión floja: es una pieza
que no se puede ni manipular. Y no lo vi porque en la 10.1 miré la lengüeta, que
era lo que había roto la vez anterior, y no volví a mirar la espiga.

### Los tres cambios, todos a la misma ecuación

La tensión en la raíz vale M/W, así que sólo hay tres palancas y se han movido
las tres: **Ø3,4 → Ø4,0** (W ×1,6), **12 → 9 mm de largo** (momento ×0,75) y
**raíz cónica de Ø4,4 en 1,5 mm** en vez de ángulo vivo (Kt de 1,8 a 1,2).
Juntas, de 0,5 a 2,4 kg.

**El acuerdo cóncavo de toda la vida no cabía.** Dos de R1,2 separados 5,6 mm se
tocan entre sí y se salen del hombro, y el rebaje que el cabezal necesitaría para
librarlos se comería la corona de apoyo entera — que es la única razón por la que
esta unión existe. La raíz cónica hace el mismo trabajo y el taladro del cabezal
la copia sin rebaje ninguno: sale gratis.

### El techo del concepto, por escrito

Con el cuerpo en Ø12, para que al cabezal le queden 1,1 mm de pared por fuera de
cada taladro y 1,45 de alma entre los dos, hace falta que separación ≥ Ø + 1,65 y
que separación + Ø ≤ 9,7. **La espiga no puede pasar de Ø4,0.** Ahí se acaba lo
que se puede reforzar sin cambiar de idea.

Así que la v10 se queda como la unión más frágil de las diez por un factor de
casi cuatro, y eso pasa al README y a la tabla de portada. Sigue teniendo la
mayor corona de apoyo —**53,5 mm²**, ha subido al separarse más las espigas— pero
la v6 da el 90 % de esa cifra con una parte macho maciza. Para casi todo el
mundo, la v6 es mejor opción.

Verificado: interferencia 0,0000 mm³; raíz medida sobre la malla Ø4,387 → Ø4,000
en 1,6 mm; garganta a Ø3,520; pared del cabezal 1,08–1,11 y alma 1,41; lengüetas
libres y boca entera comprobadas por sondeo; corona 53,46 mm². La lengüeta baja a
1,1 de pared, así que trabaja al 0,67 % en vez del 0,49 %, y sigue holgada porque
es tracción dentro de la capa.

---

## v10.3 — La v10 se rompió al imprimirla · 9 de septiembre de 2026

Jorge imprimió la v10.0. **Al apretarla mínimamente con las manos se partieron
los brazos**: primero medio brazo de cada espiga, y al sacar el cabezal, el que
quedaba. Se pudo montar «con una pata y media».

### Qué falló, y qué decía la ficha

La ficha de la v10.0 prometía 0,56 % de deformación de trabajo. **Era falso, por
dos errores míos en el mismo cálculo:**

1. Tomé como voladizo los 9 mm de ranura, cuando lo que trabaja es la distancia
   del arranque de la ranura al centro de la pestaña: 6,2 mm. Y la deformación va
   con el cuadrado del voladizo.
2. Traté la sección como un rectángulo de 1,2 mm de espesor. No lo es: es un
   **segmento circular**, y su fibra exterior está a 0,70 mm del centroide, no a
   0,60. Con 2,86 mm² de área.

El número real es **1,37 %**.

**Pero el fallo de fondo era la dirección, no el número.** El brazo es un
voladizo vertical en una pieza que se imprime de pie, así que la tracción va
**entre capas**, y ahí el PLA rompe alrededor del 1 %. Con 1,37 % no había
margen, y la pieza hizo exactamente lo que dicen los números.

### La regla que sale de aquí

**Lo que flexa va en el CABEZAL, no en el mango.** El mango se imprime de pie:
cualquier voladizo suyo flexa entre capas. El cabezal se imprime tumbado sobre su
cara de lijado, así que una lengüeta suya que flexe hacia los lados trabaja
dentro del plano de la capa, que es donde el PLA sí aguanta.

Es una regla de este proyecto, no general, y sale de la orientación de impresión
que se decidió el primer día. Va al apartado 7 del README, con las otras trampas.

### La v10.1

- **Espigas macizas**: 9,08 mm² cada una, sin ranura, sin nada que romper. Llevan
  una garganta de 0,24 de profundidad.
- **Dos lengüetas en el cabezal**, formadas por la pared exterior sobre cada
  taladro y liberadas por dos ranuras que arrancan a 2 mm de la boca — esos 2 mm
  intactos son los que salvan la corona de apoyo.
- Las espigas pasan a separarse en el eje que en el cabezal impreso es el
  **horizontal**, para que las lengüetas caigan en los costados y no en la cara
  que apoya en la cama.
- **La lengüeta abre 0,105 mm, no 0,18.** La pestaña sobresale 0,18 dentro de un
  taladro que ya es 0,075 más ancho que la espiga. Con 1,5 de pared, 3,0 de ancho
  y 7,0 de voladizo: **0,49 %**, y en el plano bueno.
- Ese mismo 0,105 es el escalón que retiene. Como la retención sale del ángulo
  del canto y no de su profundidad, el canto de arriba de la garganta se hace
  corto (0,15 para 0,24, unos 64°): retiene sin pedir más recorrido. Se gradúa
  con `esp2_gar_sube`.

Verificado: interferencia 0,0000 mm³; espigas medidas Ø3,400 a y = ±2,70 con
garganta a Ø2,920; corona de apoyo **51,55 mm²**, sigue siendo la mayor de las
diez; lengüetas comprobadas libres por siete sondeos de material/hueco, y la boca
intacta a 0,5 mm. Voladizo en la unión 103,6 mm², en línea con la v2 (97,0), y
son puentes de 3,2 mm.

### De paso, la v5

El mismo método, aplicado al clip de la v5, da **1,9 %** y no el 1,4 % que decía
su ficha. También es tracción entre capas. Se salva porque su brazo tiene
13,2 mm² de sección contra los 2,9 de la v10.0 — y porque su ficha lleva desde el
principio el aviso de imprimirlo en PETG, que ahora se entiende mejor por qué.
Corregido el número en el README.

---

## v10.2 — El visor y el kit de test, al día · 9 de septiembre de 2026

Las dos cosas que quedaban colgando de las cinco uniones nuevas.

**El visor 3D pasa de cinco versiones a diez.** 88 mallas nuevas — 16 por versión
más las piezas sueltas — y 170 empotradas en total. El archivo pasa de 1,3 a
3,0 MB, que sigue siendo un HTML que se abre de doble clic sin servidor ni nada
que descargar.

- Nuevo `web/_empaquetar.py`, que el proyecto no tenía: renderiza lo que falte,
  cuantiza a 16 bits, comprime, y arma `visor_lijador.html` desde la plantilla.
  Sin argumentos sólo hace lo que no está en `meshes.js`, así que regenerar una
  versión no cuesta las otras nueve.
- **La cuña de la v8 y el casquillo de la v9 se ven montados**, en rojo, como
  tercera malla del conjunto. Para eso hizo falta `pieza="extra_puesto"`, que
  saca la pieza suelta ya colocada en el marco del cabezal — y cuatro mallas por
  versión en vez de una, porque ese marco se mueve con el ángulo del cabezal y,
  a 90°, también con su ancho.
- Fichas nuevas para las cinco uniones, y la tabla comparativa **transpuesta**:
  con diez columnas no se leía. Ahora es una fila por unión, y una de las
  columnas es la corona de apoyo.

Verificado sin abrirlo: `node --check` sobre el script de la aplicación y sobre
las mallas, y una simulación de la interfaz que comprueba que las 10 versiones ×
15 cabezales × 3 mangos que la UI puede pedir existen todas, y que las cuatro
colocaciones de pieza suelta se resuelven para los catorce cabezales. Descodificando
las mallas empaquetadas, la cuña de la v8 cae a 7,80 mm de la boca —su `cun_z`— y
el casquillo de la v9 arranca exactamente en el plano de la boca con Ø14,60.

**El kit de test cubre las diez.** El `test_ajuste` de la v8 y la v9 sale ya con
su tercera pieza al lado, y además se genera suelta por si hay que reimprimirla
con otra holgura: es lo único que se toca al calibrar esas dos.

Diez enganches son 26 cm³ y ya no es «un rato», así que `test_rapido.sh` acepta
un subconjunto:

```bash
VERS="v10 v6 v7" ./test_rapido.sh v6
```

Ese trío es el primer corte recomendado: la v10 es la que mejor sale en cualquier
impresora, la v6 la que mejor aguanta el uso y la v7 la única sin holgura que
calibrar. Y sirve de diagnóstico: si sale bien la v10 y mal otra, el problema es
de calibración, no del diseño.

---

## v10.1 — La falda exterior, y por qué no es una mejora universal · 9 de septiembre de 2026

Opción nueva del esqueleto, `falda`, que no es una unión: el cabezal se alarga y
envuelve por fuera un tramo rebajado de la punta del mango. Con `falda = 0` —el
valor por defecto— la geometría de las diez versiones es **idéntica**, verificado
comparando volúmenes de cabezal, test y mango antes y después del parche.

La hipótesis con la que se propuso era «el momento pasa a resistirse en Ø12 en
vez de en Ø8,6, y el basculamiento cae a menos de la mitad». **Medida, resultó
ser medio verdad, y por otra razón.**

```
                  corona      inercia de la corona
v2  sin falda     1,6 mm²          22 mm⁴
v2  CON falda    30,5 mm²         420 mm⁴     ← 19 veces más
v6  sin falda    48,5 mm²         434 mm⁴
v6  CON falda    27,2 mm²         367 mm⁴     ← 15 % menos
v10 sin falda    51,6 mm²         415 mm⁴
v10 CON falda    27,2 mm²         367 mm⁴     ← 12 % menos
```

La falda cambia un disco casi macizo por un anillo: gana radio y pierde área.
A las uniones cuya boca acaba en filo (v2 a v5) las rescata; a las que ya tienen
disco (v6, v10) les quita un poco. **No es una mejora universal, y la primera
versión del cálculo no lo veía porque estimaba la corona en vez de medirla.**

Lo que sí vale para todas es lo otro: sin falda al cabezal lo guía sólo el
taladro —13 mm de base, 0,18 de holgura, 1,59° de bamboleo—; con falda hay dos
guías, una a cada lado del plano de la junta, la base pasa a 19 mm y quedan
0,84°. Ahí sí se cumple lo de «la mitad», pero por alargar la base, no por el
diámetro.

Cuesta 6 mm de herramienta y ~220 mm³ por cabezal.

### El mismo fallo, por tercera vez

La primera versión de la falda tenía `falda_pared` 1,2 y `falda_chaflan` 0,6.
Resultado: contrataladro Ø9,8, avellanado hasta r = 5,5 y borde exterior en
r = 5,2 — **corona negativa, boca en filo otra vez**. Es el fallo de la v2.2 y el
de la v8, y van tres. Con `falda_pared` 1,6, `falda_chaflan` 0,3 y un chaflán de
boca propio de 0,3 en vez del `cuerpo_chaflan` de 0,8, la corona sale de 30,5 mm².

La regla, ya escrita en el README: **la suma del avellanado interior y el chaflán
exterior tiene que dejar anillo.** Es lo primero que hay que comprobar al tocar
cualquier cota de la boca.

### Dos incompatibilidades, comprobadas

- **v7:** la corona de la falda apoyaría en el hombro y le disputaría al cono el
  posicionamiento axial, que es exactamente lo que esa unión evita a propósito.
- **v9:** el cono exterior de la pinza queda enterrado 6 mm dentro de un tubo de
  Ø12 —medido: Ø11,12 a 7 mm de la boca, Ø11,62 a 11 mm— y el casquillo no puede
  llegar a él. Renderiza sin error y no sirve para nada, que es la peor clase de
  fallo.

También se ajustó `plano_efectivo()`: con falda, el plano antirrodadura del mango
doble lo limita la espiga rebajada, que es más gorda que cualquier vástago y
sería lo primero en cortarse.

---

## v10.0 — Doble espiga, y la corona de apoyo medida en las diez · 9 de septiembre de 2026

Décima unión: dos espigas de Ø3,4 separadas 5,4 mm, cada una partida en dos
brazos con una pestaña de 0,25 que hace clic. Reparte el trabajo — las espigas
orientan y aguantan par y cortante, las pestañas sólo retienen — y deja que
quien impida bascular sea el hombro.

- **51,6 mm² de corona de apoyo, la mayor de las diez.** Cambiar un taladro de
  Ø8,6 por dos de Ø3,55 convierte la boca del cabezal de un anillo fino en un
  disco casi macizo. La v2 tiene 1,6.
- **La más fácil de imprimir bien:** dos postes redondos y dos agujeros
  redondos. Sin hélices, destalonados, tetones en canal ni paredes finas.
- Brazos al **0,56 %** de deformación contra el 1,4 % del clip de la v5: flexar
  está repartido entre cuatro brazos en vez de dos.
- Simétrica: entra en dos posiciones giradas 180°.
- Espigas separadas en el eje que en el cabezal impreso es el vertical, para que
  su par de fuerzas se oponga a la flexión de la presión de lijado.
- Juego de giro 1,6° (holgura ÷ semiseparación). Con `esp2_holgura` a 0,05, 1,1°.
- Lo que cuesta: espigas esbeltas. Mientras apoye la corona da igual; haciendo
  palanca de verdad, Ø3,4 es lo que hay.

### La medición que cazó un fallo en la v8

Para poder afirmar lo de los 51,6 mm² había que medirlo, y medirlo en las diez.
Integrando sobre la malla el material del cabezal en el plano de la boca,
recortado a lo que alcanza el hombro:

```
v10 doble espiga .... 51,6 mm²      v4  imán ............  8,9 mm²
v6  cola de milano .. 48,4 mm²      v9  pinza ...........  8,5 mm²
v1  hexágono ........ 25,5 mm²      v2  bayoneta ........  1,6 mm²
v5  clip ............ 13,4 mm²      v3  rosca ...........  0,0 mm²
v8  cuña ............ 13,2 mm²      v7  cono ............  0,0 mm²  (a propósito)
```

**La v8 salía con 0,63 mm².** El avellanado de su boca era de 0,8 y se comía el
borde que deja `cuerpo_chaflan`: la boca acababa en filo, exactamente el fallo
que costó la v2.2 — y en la unión donde más duele, porque el hombro es contra lo
que aprieta la cuña. Corregido con un parámetro propio, `cun_avell` = 0,4: 13,2
mm² de cara plana. La v8 pasa a 8.1.

Los ceros de la v3 y la v7 no son iguales: el de la v7 es de diseño, porque ahí
posiciona el cono y el hombro tiene prohibido tocar.

Verificado: interferencia 0,0000 mm³ en la v8 corregida y en la v10 (contacto de
corona, espesor nulo). Espigas medidas sobre la malla: Ø3,400 a x = ±2,70,
pestaña de 0,248. Todas las piezas `Simple: yes`. Voladizo en la unión 69,1 mm²,
por debajo de la v2 (97,0).

`stl/v10/test_ajuste.stl` listo. Sin imprimir todavía.

---

## v9.0 — Pinza cónica · 9 de septiembre de 2026

Novena unión: una pinza de portaminas. La boca del cabezal partida en cuatro
dedos por ranuras axiales, exterior cónico 1:8, y un casquillo de Ø14,6 × 6 mm
(355 mm³) que se empuja con el pulgar y los cierra sobre el vástago.

Hace lo mismo que la v8 —apriete regulable que no se agota— **sin pieza que se
pueda perder**: el casquillo no puede pasar al mango por detrás (taladro trasero
Ø11,05 contra un mango de Ø12) ni al cuerpo del cabezal por delante. Sólo sale
con el cabezal desmontado.

- 2 mm de recorrido, 0,125 mm de cierre de diámetro por milímetro. La unión se
  reaprieta durante toda la vida de la herramienta.
- Deformación de trabajo del dedo: **0,4 %**. Cierra 0,075 mm sobre un voladizo
  útil de 6 mm con 1,3 de pared. El clip de la v5 trabaja al 1,4 %.
- Cada ranura acaba en un taladro de alivio de Ø1,4, que es lo que evita que el
  dedo agriete donde la ranura moriría en ángulo vivo.

**La pinza va en el cabezal y no en el mango, y hubo que decidirlo antes de
modelar nada.** Con la pinza en el mango los cabezales necesitarían un vástago
macho saliendo en horizontal de la boca y dejarían de imprimirse planos sobre su
cara de lijado — la decisión de la que cuelga el proyecto entero. Invertida, sale
gratis: el mango queda como un cilindro liso de Ø8,6, el más simple de las nueve
versiones, y cualquier cabezal se puede montar sobre cualquier varilla de ese
diámetro.

**Lo que cuesta:** un collar de Ø14,6 en una herramienta de Ø12, y cuatro ranuras
abiertas en el cabezal que recogerán polvo.

### El chaflán que se comió la pieza

`difference() { cylinder(d=14,6, h=6); ... cylinder(r1=R+0,5, r2=R−0,5, h=0,5); }`
parece un chaflán y no lo es: en z=0 el radio de ese cono es mayor que el de la
pieza, así que el primer plano del casquillo desaparece entero. La envolvente lo
cantó —5,51 mm de alto en una pieza de 6— pero a ojo, en el render, no se veía.
Un chaflán se resta como **anillo**: la diferencia entre un cilindro grande y el
cono, no el cono a secas.

Verificado: casquillo ∩ cabezal y casquillo ∩ mango, las dos intersecciones
vacías con el casquillo en reposo; cabezal ∩ mango = 0,0 mm³ (contacto de corona,
espesor nulo). Cono exterior medido sobre la malla: 0,125 mm/mm, exacto. Todas
las piezas `Simple: yes`. Voladizo en la unión 101,3 mm², en línea con la v2
(97,0) y la v8 (95,4).

`stl/v9/test_ajuste.stl` incluye el casquillo. Sin imprimir todavía.

---

## v8.0 — Espiga y cuña transversal · 9 de septiembre de 2026

Octava unión, y la primera con **tres piezas**: mango, cabezal y una cuña de
13,6 × 5 × 2,6–3,2 mm (177 mm³). La de carpintería de siempre, a escala de
bolígrafo.

El vástago lleva una ranura transversal y el cabezal un túnel alineado. La cuña
los atraviesa: apoya abajo en el suelo del túnel del cabezal y arriba en el techo
de la ranura del vástago, y como es cónica 1:12, empujarla separa esas dos caras
y tira del vástago hacia dentro, apretando el cabezal contra el hombro.

- **Apriete regulable, que es lo que ninguna otra tiene.** No lo fija un número
  del modelo: lo fijas empujando. 7,2 mm de recorrido por delante. Si dentro de
  un año baila, se empuja medio milímetro más en vez de reimprimir catorce
  cabezales.
- **La cuña es también la chaveta**, así que el taladro puede ser un cilindro
  liso. Con 13,6 mm de largo, sus 0,08 de holgura lateral sólo permiten 0,34° de
  descuadre: lo que fija el giro es el largo de la cuña, no su ajuste.
- **La cuña es el fusible.** Aguanta ~90 N de precarga antes de doblarse y la
  ventaja mecánica es 12:1, así que es lo que rompe si te pasas apretando. Es la
  pieza más barata de reimprimir del proyecto, y prefiero que ceda ella.

### El coste, medido en vez de estimado

Es la unión que más debilita el cabezal, y merecía números en vez de adjetivos.
Sección del cuerpo en la banda del túnel contra la sección intacta, integrando
sobre la malla:

```
                            área      I (presión de lijado)   I (lijando de lado)
intacta, a 4 mm de la boca  49,3 mm²        659 mm⁴                706 mm⁴
en la banda de la cuña      32,7 mm²        621 mm⁴                288 mm⁴
pérdida                        34 %           5,7 %                   59 %
```

**La orientación del túnel resultó ser la buena por una razón que no era la que
me llevó a ella.** Se eligió porque así los flancos salen verticales al imprimir;
resulta que además el túnel quita material del eje neutro para la flexión que
produce la presión de lijado —la carga dominante— y sólo cuesta 5,7 % de inercia.
Girado 90° sería exactamente al revés. Como el momento en la banda es el 75 % del
de la boca, lijando de plano la banda trabaja al 0,80 de lo que trabaja la boca:
**no es la sección crítica.** Lijando de lado sí lo es, a ~1,8 veces la tensión
de la boca, pero ahí las fuerzas son de rozamiento, no de presión.

El túnel está a 7,8 mm de la boca: lo más adentro posible sin llegar a los 13 mm
donde arranca el cuello de la pala.

### El esqueleto ahora admite piezas sueltas

Una unión de tres piezas no cabía en el generador. Se añaden dos módulos
opcionales, vacíos en las otras seis: `junta_extra()` saca la pieza tumbada para
imprimir con `pieza="extra"`, y `junta_extra_montado()` la coloca en el marco de
la boca. El `test_ajuste` la incluye al lado del macho y la hembra, y el
`conjunto` la pinta montada. v2–v7 regeneradas y verificadas sin cambios.

Verificado: cuña ∩ cabezal = intersección vacía; cuña ∩ mango = 0,0 mm³ con
contacto en las dos caras de trabajo; cabezal ∩ mango = vacía. Todas las piezas
`Simple: yes` y estancas. Voladizo en la unión 95,4 mm², prácticamente el mismo
que la v2 (96,9), que ya está impresa y sale bien.

`stl/v8/test_ajuste.stl` incluye la cuña. Sin imprimir todavía.

---

## v7.0 — Cono autoblocante · 9 de septiembre de 2026

Séptima unión: un cono de 12° de semiángulo, Ø8,4 × 9 mm, con dos planos de
chaveta. Es la v1 hecha bien.

**Sin holgura que calibrar, que es todo el argumento.** Un cilindro necesita
hueco para entrar y ese hueco es el juego con el que baila después; un cono se
para donde le deja la interferencia y queda tocando en toda la superficie. El
error de impresión se convierte en profundidad de asiento en vez de en juego.

- Autorretenedor: 12° está por debajo del ángulo de rozamiento del PLA (~17°).
  Queda firme y sale de un tirón; a 7° agarraría más pero habría que golpearlo.
- Los planos de chaveta son **cónicos** también: escalan con el cono y aprietan
  con él, así que el giro tampoco tiene juego. Unos planos paralelos al eje se
  separarían de su cara en cuanto la profundidad de asiento variase.
- El cabezal **no apoya en el hombro**: quien posiciona es el cono. El chaflán
  frontal sube a 1,7 mm para que la punta del mango (Ø8,60) y el anillo de la
  boca (Ø9,63) no puedan tocarse.

**La contrapartida, sin adornos:** la profundidad de asiento depende del ajuste
—0,47 mm por cada 0,1 mm de error radial— y como un taladro impreso en
horizontal sale estrecho, lo esperable es medio milímetro de junta entre las dos
piezas. No afecta a cómo sujeta y `con_retro` la cierra.

### Tres cosas que sólo salieron al medir

**El taladro estaba desplazado al revés.** `translate([0,0,-con_asiento])` sobre
un cono que se estrecha lo hace más *estrecho* en la boca, no más ancho: 10,4 mm³
de interferencia repartidos por toda la superficie cónica, que es justo el
número que sale de multiplicar 0,049 mm por los 271 mm² de la generatriz.

**A 7° la profundidad de asiento se movía el doble.** Con 0,1 mm de error radial
el cabezal se iba 0,81 mm; a 12° son 0,47. Y el ángulo pequeño multiplica por 8
la fuerza de cuña sobre una pared de 1,6 mm. Subir a 12° cuesta muy poco agarre
—sigue muy por debajo del ángulo de rozamiento— y arregla las dos cosas.

**El cuello era un cilindro y se comía los planos.** El rebaje que hay antes del
cono, para que la boca del cabezal pueda pasar si el ajuste sale suelto, era un
cilindro de revolución: invadía la zona de los planos del taladro (2,5 mm³ de
interferencia, todos en el primer milímetro) y de paso dejaba ahí la sección más
débil de la pieza. Ahora es el mismo perfil rebajado 0,3 mm en radio, con enlace
a 45° para no dejar voladizo al imprimir el mango.

Verificado: `pieza="interferencia"` = 0,0004 mm³ — macho y hembra son
literalmente el mismo cono. Semiángulo medido sobre la malla: 12,00°. Planos a
3,193 mm en la base contra 3,193 de diseño. Todas las piezas `Simple: yes`.
Y menos voladizo en la unión que la v2: 54,8 mm² contra 96,9, porque el cono es
más corto y más estrecho que el vástago de la bayoneta.

`stl/v7/test_ajuste.stl` listo. Sin imprimir todavía.

---

## v6.0 — Cola de milano transversal · 8 de septiembre de 2026

Sexta unión, y la primera que no se enchufa: el cabezal **desliza de lado** sobre
un carril de cola de milano en la punta del mango.

La pregunta de la que sale es «¿qué enganche aguanta el movimiento de lijar en
todas las direcciones?». Las cinco anteriores resisten el desmontaje; ésta lo
evita: empujar y tirar actúan a lo largo del mango, girar alrededor de él, y el
cabezal sale perpendicular a las dos. El gesto de lijar no puede desmontarlo.

Carril de 7,0 × 5,0 mm, flancos a 12° de la vertical, recorrido de 7,9 mm.

- **El tirón lo aguanta la forma.** El destalonado de 12° hay que romperlo para
  separar las piezas. No depende del rozamiento (v1, v4), ni de un brazo elástico
  que se fatiga (v5), ni de que la holgura siga siendo la del primer día. Un
  carril tampoco gira dentro de su ranura.
- **Cónico:** la cresta se estrecha 0,7 mm de la entrada al tope (0,095 mm/mm) y
  la ranura del cabezal igual. Entra suelta y sólo aprieta en el último
  milímetro; por el ángulo del milano, ese apriete empuja el cabezal contra el
  hombro. Misma cuña autoblocante que la bayoneta de la v2, en línea recta.
- **Retención en el sentido del deslizamiento:** tope duro por delante y resalte
  de 0,10 mm en la entrada del carril por detrás. Para pasarlo el cabezal se
  levanta ~0,45 mm del hombro, así que se nota como un clic. Va en la ENTRADA a
  propósito: sólo queda cubierto en los últimos 1,5 mm y no roza durante todo el
  recorrido, que es lo que pasaría con el resalte en cualquier otro sitio.

**Nació imposible de imprimir.** Con la unión en su orientación natural —el
cabezal entrando de lado— los flancos del milano quedan a 12° de la *horizontal*:
un voladizo de 78° de 105 mm², y justo sobre la superficie de ajuste. Girando la
unión 90° sobre el eje de la herramienta (`cm_orient = 90`) los flancos salen
verticales, el cabezal baja a 1,6 mm² de voladizo en la zona de la unión (la v2
tiene 4,6) y, de propina, la presión de lijado pasa a meter el cabezal contra su
tope en vez de sacarlo. El parámetro sigue ahí por si alguien prefiere el
deslizamiento lateral y no le importa poner soportes.

Y un corolario del espejo entre marcos que no estaba documentado: **para girar
una unión sobre el eje hay que girar macho y hembra en sentidos contrarios.** Con
el mismo signo, la parte simétrica encaja y la conicidad sale invertida.

Verificado: `pieza="interferencia"` da 0,0001 mm³ con `cm_aprieto = 0` (macho y
hembra casan exactos) y 1,08 mm³ con los valores por defecto, que es el apriete
buscado. Mango, cabezal y `test_ajuste` salen `Simple: yes` y estancos. Medido
sobre la malla: destalonado de 1,95 mm en 4,8 de altura (12,0°), conicidad de
0,095 mm/mm creciendo hacia el tope, y resalte de 0,10 mm por flanco entre
x = −3,97 y −2,97.

`stl/v6/test_ajuste.stl` listo para imprimir. Falta imprimirla: es la única
versión de la familia que todavía no ha pasado por la cama.

---

## Los scripts de render fallaban en silencio · 8 de septiembre de 2026

`./render.sh v2` recorría las 18 piezas, no escribía ni un fichero y terminaba
diciendo «Listo»: la llamada a OpenSCAD acabab en `2>&1 | grep -E "ERROR" || true`,
que se traga también el «command not found».

- Los dos scripts comprueban que OpenSCAD existe antes de empezar, y que cada STL
  se ha escrito y no está vacío. Si falta algo, salen con código 1.
- Nuevo `render.ps1`: el mismo render desde PowerShell, sin Git Bash ni WSL, con
  búsqueda de `openscad.exe` en el PATH y en las rutas de instalación normales.
- Calidad final pasa de `$fn=96` a **64**. En un cilindro Ø12 el error de facetado
  es de 0,007 mm contra 0,003 — los dos muy por debajo de lo que puede expresar una
  boquilla de 0,4 — y con 96 el mango tarda tres veces más en resolver los booleanos
  (más de tres minutos por pieza).

Y renderizadas las 18 piezas de la v2.2 a `stl/v2/`: 88,7 cm³, las 18 estancas
(0 aristas de borde, 0 no-manifold) y dentro de 180 × 180 × 180 mm.

---

## v2.2 — El cabezal no llegaba a apoyar en el hombro · 8 de septiembre de 2026

Con la v2.1 impresa, el `test_ajuste` sujetaba bastante mejor que el `mango_corto`.
La unión es idéntica en las dos piezas, así que la diferencia tenía que estar en el
hombro. Medido sobre las mallas, el radio hasta donde llega material en el plano de
la boca:

```
                        arranca la cara     borde exterior    hombro del mango
v1 hexágono ........... r = 3,95            r = 5,20          4,30 – 5,00   apoya
v2 bayoneta ........... r = 5,28            r = 5,20          4,30 – 5,00   NO
v3 rosca .............. r = 5,40            r = 5,20          4,30 – 5,00   NO
v4 imán ............... r = 5,50            r = 5,20          4,30 – 5,00   NO
v5 clip ............... r = 5,30            r = 5,20          4,30 – 5,00   NO
```

En las cuatro últimas el avellanado de la boca es más ancho que el borde que deja
el `cuerpo_chaflan`: **no hay cara plana, la boca acaba en filo**, un anillo vivo a
r = 5,24 y 0,04 mm por dentro del plano. Y el `mango_chaflan_frontal` de 1,0 mm
dejaba el hombro en r = 5,00, así que ese filo caía sobre el chaflán, 0,28 mm por
debajo: no se tocaban. El cabezal iba en voladizo sobre el vástago, sujeto sólo por
el tetón, y el par de lijar lo hacía bascular dentro de la holgura.

El tapón del `test_ajuste` es un cilindro Ø12 a secas, sin chaflán: apoya en todo
el anillo. Por eso engañaba.

- v2: `mango_chaflan_frontal` 1,0 → **0,3**, en el bloque de la v2, no en el
  esqueleto. Hombro hasta r = 5,70: el filo del cabezal cae dentro del plano, con
  0,04 mm nominales de separación que la tolerancia de impresión cierra.
- v2: `ergo_d_frente` 11 → **11,6**. El mango ergonómico arranca más fino que el
  recto, así que con el chaflán se quedaba en r = 5,20 — 0,04 corto — y era el
  único de los tres que seguía sin apoyar.
- En la variante **doble** la culata también es un hombro: pasa a llevar el chaflán
  frontal en los dos extremos, no el de 1,5 mm. Esto sí toca las cinco versiones,
  pero sólo a esa variante de mango.

Los tres mangos de la v2, medidos sobre la malla (borde del cabezal, r = 5,24):

```
recta ........ hombro r = 4,30 – 5,70   apoya
ergonómica ... hombro r = 4,30 – 5,50   apoya  (antes 5,20)
doble ........ hombro r = 4,30 – 5,70   apoya
```

**Sólo cambia el mango de la v2.** Los cabezales no cambian, y las otras cuatro
versiones sólo cambian si imprimes el mango doble.

Pendiente: el apoyo de la v2 sigue siendo un filo, no una cara. Convertirlo en un
anillo plano de 0,3-0,7 mm pide bajar `cuerpo_chaflan` de 0,8 a 0,4 — y eso ya es
reimprimir los catorce cabezales, así que espera a que haya más motivos para
hacerlo.

Lección para el `test_ajuste`: reproduce la unión, pero no el hombro real del
mango. Vale para calibrar holguras, no para juzgar cuánto agarra.

---

## v2.1 — La bayoneta deja de aflojarse · 8 de septiembre de 2026

Lijando de lado, la v2.0 se soltaba. La causa no era la cuña sino el juego axial
del canal, que estaba fijado a mano en 0,15 mm:

```
espesor del tetón .................. 2,60 mm
alto del canal en el asiento ....... 2,72 mm   →  0,12 mm de flotación
alto del canal bajo la muesca ...... 2,66 mm   →  aprieto real  −0,06 mm
```

Es decir: el tetón flotaba, la cuña no llegaba a apretar contra nada y la muesca
de retención pasaba por debajo sin tocarla. El «clic» era el rozamiento de las
paredes, no un resalte. Un par alterno — que es exactamente lo que hace lijar de
izquierda a derecha, 10-15 N a 5,5 mm del eje ≈ 55-80 N·mm — se lo lleva por
delante en unas cuantas pasadas.

Cambios, todos en la parte macho:

- `bay_juego_ax` deja de estar escrito a mano en `bay_ranura()` y pasa a ser
  parámetro, con valor **0,05**. El tetón queda pinzado (0,02 mm de holgura).
- `bay_muesca` 0,06 → **0,18**. Ahora muerde 0,16 mm reales: salir del asiento
  exige deformar el vástago, no vencer un rozamiento.
- `bay_rampa` 0,25 → **0,40**, más recorrido de cuña con el que precargar.

**Sólo hay que reimprimir el mango**: el cabezal no cambia ni un micrómetro.

Descartado por el camino: dientes rígidos en el hombro. Sacar un diente de 0,5 mm
exige separar el cabezal 0,5 mm, y el canal cerrado sólo da 0,12; desenroscar para
ganar hueco tampoco vale, porque la hélice del canal sube 5,4° y el flanco del
diente 60°. Sería un bloqueo mutuo: se monta y no sale. Con dientes rígidos el
desmontaje tendría que ser «tirar y girar», con muelle o imán — anotado como
posible v7.

---

## Kit de test rápido · 8 de septiembre de 2026

Añadidos `test_rapido.sh`, `TEST_RAPIDO.md` y la carpeta `stl_test/` (24 piezas,
68 cm³ en total, repartidas en tres pasos de ~1 h cada uno). No cambia ninguna
pieza del modelo: es el mismo `.scad` con `mango_largo=30`, `largo_pala=18` y
`largo_barra=18`, para probar los cinco enganches y las siete formas sin imprimir
el juego entero.

La geometría de unión no se toca. Comprobado con `pieza="interferencia"` sobre el
mango corto de la v2: 0,11 mm³ de solape, el aprieto de diseño de la bayoneta.
Las 24 mallas son estancas (0 aristas de borde, 0 no-manifold).

---

## v1.0 — Hexágono a presión · 7 de septiembre de 2026

Primera versión completa. **Congelada** en `sanding_stick_v1.0.zip`.

Espiga hexagonal de 6 mm entrecaras a presión, espiga en el mango y hueco en el
cabezal. Holgura 0,15 mm por lado, 12 mm de agarre, chaflanes de 0,8 mm.

18 piezas: 3 mangos + 14 cabezales + pieza de calibración. Las 18 estancas, todas
dentro de 180 × 180 × 180 mm.

Correcciones durante el desarrollo:

- `cabezal_pala_8_45`: 8 aristas no-manifold por tangencia entre la superficie
  reglada del cuello y el cilindro del cuerpo → base del cuello reducida a Ø11,4 mm.
- `cabezal_triangulo_8`: vértices sin fusionar en el hombro → hombro rediseñado como
  `hull()` de un círculo Ø12 hacia el ancho de la pala.

## v2.0 — Bayoneta de 1/4 de vuelta

Vástago Ø8,6 con dos ranuras en L y taladro Ø8,96 con dos tetones. El canal es
helicoidal: su techo baja 0,25 mm a lo largo del giro, de modo que **girar aprieta**
el cabezal contra el hombro. Cuña autoblocante, con un resalte de 0,06 mm que da el
clic al entrar en el asiento y un tope duro al final.

- Los tetones a ±90° (horizontales sobre la cama) → cero voladizos en el cabezal.
- Diámetro elegido para que la sección crítica del canal aguante: Ø6,36 en el fondo
  de la ranura, ~21 MPa a 20 N de empuje, el doble de margen.
- Encaje verificado por volumen: 0 mm³ en la posición de inserción, 0,111 mm³ (el
  apriete buscado) en la posición bloqueada.

## v3.0 — Rosca cuadrada Ø8 × paso 2

Seis vueltas de filete cuadrado de 0,7 mm, piloto liso Ø8,6 × 2 que centra antes de
engranar, hombro plano de apoyo. Holgura 0,25 radial + 0,15 axial por flanco.

Dos fallos encontrados y corregidos:

- La hembra y el piloto sólo se **tocaban** en un plano → CGAL dejaba el taladro como
  cavidad cerrada. Resuelto bajando la hélice un paso entero dentro del piloto.
- **Quiralidad:** el marco de la boca del cabezal está espejado en Z, así que la
  hélice de la hembra salía a izquierdas contra un macho a derechas (44 mm³ de
  interferencia). Resuelto invirtiendo la hélice y girándola 180°.

## v4.0 — Imán Ø6×3 + espiga en D

Espiga Ø9 × 7,5 con cara plana antigiro y un imán de neodimio en la punta; otro
imán al fondo del taladro, con 0,3 mm de separación entre caras al montar.
Requiere 15 imanes (uno por mango y por cabezal) pegados con cianoacrilato.

- Mismo fallo de cavidad cerrada que la v3 en el alojamiento del imán, resuelto
  solapando 0,4 mm el alojamiento dentro del taladro.
- Encaje verificado: 0,000 mm³ de interferencia.

## v5.0 — Clip elástico de dos brazos

Vástago partido por una ranura de 3,8 mm en dos brazos de 11,5 mm de voladizo, con
pestañas de 0,6 mm y rampas de 40° a ambos lados. Dos caras planas orientan y hacen
de chaveta.

- Dimensionado por deformación: ~1,4 % en el brazo al montar, dentro de lo admisible
  para PLA y holgado para PETG (el material recomendado).
- Los rebajes del cabezal van a ±90°, horizontales sobre la cama, igual que los
  tetones de la v2 y por la misma razón.

---

## Estado de verificación (90 piezas)

| | Piezas | Estancas | Interferencia macho/hembra | Volumen total |
|---|---|---|---|---|
| v1 | 18 | 18/18 | — | 90,9 cm³ |
| v2 | 18 | 14/18 · resto con duplicados <10 µm | 0,111 mm³ (apriete) | 88,2 cm³ |
| v3 | 18 | 18/18 | 0,000 mm³ | 89,2 cm³ |
| v4 | 18 | 17/18 · 1 con duplicados <10 µm | 0,000 mm³ | 90,3 cm³ |
| v5 | 18 | 18/18 | 0,016 mm³ (apriete) | 87,3 cm³ |

OpenSCAD reporta `Simple: yes` —sólido 2-manifold válido— en las 90 piezas. Los
«duplicados <10 µm» son vértices que el exportador de STL ASCII escribe dos veces
con 0,003–0,01 mm de diferencia en los bordes del canal de la bayoneta; cualquier
laminador los fusiona sin avisar y no afectan a la impresión.

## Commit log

2026-09-07 Sanding Stick: lijador modular paramétrico con cinco tipos de unión
    Mango tipo bolígrafo y 14 cabezales intercambiables para lijar impresiones 3D
    y filigranas en madera, modelados en OpenSCAD para Bambu Lab A1 Mini.
    Cinco versiones que sólo se diferencian en el enganche mango-cabezal:
    v1 hexágono 6 AF a presión
    v2 bayoneta de 1/4 de vuelta con canal helicoidal autoblocante
    v3 rosca cuadrada Ø8 x paso 2
    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
    [sanding_stick.scad, sanding_stick_v2.scad, sanding_stick_v3.scad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]
2026-09-07 Añade instrucciones para publicar el repositorio
2026-09-07 Configura el remoto origin y concreta las instrucciones de publicación
2026-09-07 Ajusta el árbol de archivos del README tras mover el proyecto
2026-09-07 render.sh exporta STL binario; corrige las instrucciones para PowerShell
    El bloque de conversión a binario usaba un heredoc de bash (python3 - <<'EOF'),
    que PowerShell no entiende. Se elimina: OpenSCAD exporta directamente en binario
    con --export-format binstl, así que no hace falta convertir nada después.
    Se añade además la nota de que render.sh necesita Git Bash o WSL en Windows, y
    la forma de expandir el comodín de 'gh release' en PowerShell.
2026-09-08 Añade el kit de test rápido para elegir enganche y formas
    test_rapido.sh genera 24 piezas recortadas (mango 30 mm, cara útil 18 mm) en
    stl_test/: los cinco enganches y las siete formas, en tres pasos de ~1 h de
    impresión en vez de las cinco horas del juego completo.
    La geometría de unión no cambia. Comprobado con pieza="interferencia" sobre el
    mango corto de la v2 (0,11 mm³, el aprieto de diseño de la bayoneta) y las 24
    mallas salen estancas.
    stl_test/ va al .gitignore: es una salida regenerable, como preview_stl/.
2026-09-09 Añade cinco uniones nuevas (v6–v10) y la falda exterior opcional
    v6 cola de milano transversal — el cabezal desliza de lado, así que la
    dirección de desmontaje no coincide con ninguna dirección de lijado. El
    tirón lo aguanta un destalonado de 12°, no el rozamiento.
    v7 cono autoblocante de 12° — la única sin holgura que calibrar: el error de
    impresión se convierte en profundidad de asiento, no en juego.
    v8 espiga y cuña transversal — apriete regulable con 7 mm de recorrido, y la
    cuña hace además de chaveta.
    v9 pinza cónica de cuatro dedos — como la v8 pero sin pieza que se pueda
    perder; a cambio el mango queda como un cilindro liso.
    v10 doble esp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
    [sanding_stick.scad, sanding_stick_v10.scad, sanding_stick_v2.scad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]
2026-09-09 Regenera el visor 3D con las diez versiones
    88 mallas nuevas, 170 en total. El archivo pasa de 1,3 a 2,9 MB y sigue
    abriéndose de doble clic, sin servidor.
    La cuña de la v8 y el casquillo de la v9 se ven montados, como tercera malla
    del conjunto. Para eso hace falta pieza="extra_puesto", que saca la pieza
    suelta ya colocada en el marco del cabezal — y cuatro mallas por versión en vez
    de una, porque ese marco se mueve con el ángulo del cabezal y, a 90°, también
    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
2026-09-09 Refuerza la raíz de las espigas de la v10, que se partió por la base
    Segunda rotura de esta unión: con las espigas ya macizas, una se partió por el
    arranque al despegar la pieza de la cama.
    La raíz es un voladizo vertical en una pieza impresa de pie, así que trabaja
    entre capas, y además llegaba al hombro en ángulo vivo. Con Ø3,4 × 12 eso son
    5,4 N de fuerza lateral en la punta: medio kilo. No es una unión floja, es una
    pieza que no se puede manipular.
    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
    [sanding_stick_v10.scad, test_ajuste.stl]
